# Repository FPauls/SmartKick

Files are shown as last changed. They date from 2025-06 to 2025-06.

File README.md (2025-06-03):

# SmartKick - Intelligente Tischkicker-Zählung

## 🏆 Übersicht

<div align="center">
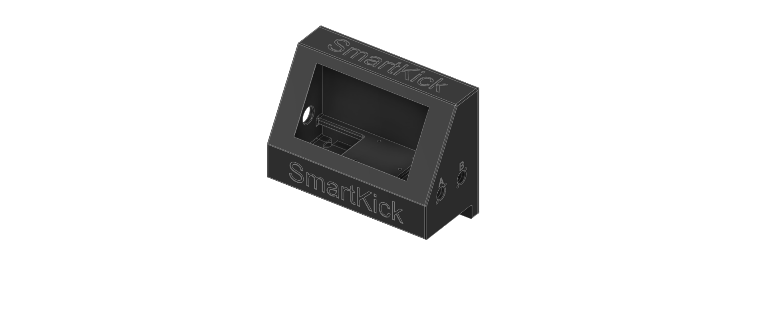
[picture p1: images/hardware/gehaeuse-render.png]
SmartKick Gehäuse

<br>
<em>SmartKick System - 3D-gedrucktes Gehäuse mit Touch-Display</em>
</div>

**SmartKick** verwandelt jeden Standard-Tischkicker in ein intelligentes Spielsystem mit automatischer Torerkennung und professionellem Touch-Display.

## ✨ Features

### 🎮 **6 Spielmodi**
<div align="center">
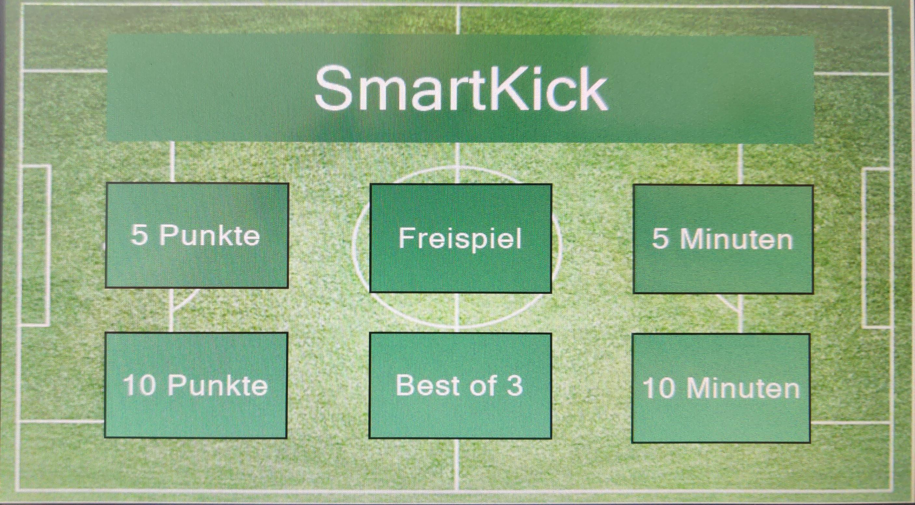
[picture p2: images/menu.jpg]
Touch Display

<br>
<em>7" Nextion Touch-Display mit intuitiver Bedienung</em>
</div>

- **🆓 Freispiel** - Unbegrenztes Training
- **⏰ Zeitspiel** - 5 oder 10 Minuten mit Countdown
- **🏆 Klassisch** - Erstes Team zu 5 oder 10 Punkten
- **🥇 Best of 3** - Schnelle Entscheidungsspiele

## 🛠️ Hardware-Komponenten

**Professionelle Komponenten für zuverlässigen Betrieb:**
- **7" Nextion Touch-Display** - Intuitive Bedienung
- **Arduino Uno Rev 3** - Zuverlässige Steuerung  
- **IR-Lichtschranken** - 99%+ Torerkennungsrate
- **10.000mAh Powerbank** - 3+ Stunden Spielzeit
- **3D-Gehäuse** - Robust und servicefreundlich

**Gesamtkosten: ~260€** (ohne Personalkosten)

**[→ Detaillierte Teileliste & Verkabelung](docs/HARDWARE.md)**

### 🔋 **Portabel & Robust**
- **3+ Stunden Akkulaufzeit** mit 10.000mAh Powerbank
- **USB-C Laden** während dem Spielen + **Smartphone-Ladefunktion**
- **3D-gedrucktes Gehäuse** - 5mm Wandstärke, Serviceklappe an Rückseite
- **Schlüsselschalter** - Schutz vor unbefugter Nutzung
- **DIN-Steckverbindungen** - modularer Aufbau, einzelne Komponenten tauschbar

### ⚡ **Automatische Torerkennung**
- **IR-Lichtschranken** (Adafruit ADA2168) mit 99%+ Zuverlässigkeit
- **5mm IR-Sensoren** in jedem Tor mit DIN-Anschluss
- **Automatische Kalibrierung** gegen Umgebungslicht
- **Debounce-Algorithmus** filtert Störungen und Vibrationen
- **Manuelle Korrektur** über +/- Buttons möglich

### 🏗️ **Technische Spezifikationen**
- **Betriebstemperatur**: 0°C bis 40°C (Gastronomie-tauglich)
- **Energiebedarf**: Maximal 5V bei 2A
- **Gehäuse**: 100% recycelter Kunststoff, 5mm Wandstärke
- **Überlastschutz**: Automatisches Herunterfahren bei Stromüberlastung
- **Langzeittests**: 100+ Stunden Betrieb erfolgreich getestet
- **Normen**: CE-Norm, VDE 0701-0702 konform

### 🔧 **Nachrüstung & Service**
- **Plug & Play** - keine dauerhafte Installation am Tischkicker
- **Klettverschluss** oder **Schraubverbindung** zur Befestigung
- **Serviceklappe** für einfachen Komponententausch
- **Modularer Aufbau** - defekte Teile einzeln austauschbar

## 🚀 Schnellstart

### 1. **Hardware aufbauen**
```
Arduino → Nextion Display → IR-Sensoren → Powerbank
```
**[→ Detaillierte Hardware-Anleitung](docs/HARDWARE.md)**

### 2. **Software flashen**
```
SmartKick.ino → Arduino IDE → Upload
```
**[→ Software-Installation](docs/SOFTWARE.md)**

### 3. **System starten**
<div align="center">
Menü Screenshot
<br>
<em>Nach dem Start erscheint automatisch das Menü</em>
</div>

- **Powerbank einschalten**
- **USB-C einstecken** 
- **Spielmodus wählen** → Sofort losspielen!

**[→ Vollständige Bedienungsanleitung](docs/USAGE.md)**

## 🎯 Für wen ist SmartKick?

### 🏢 **Unternehmen**
- **Mittagspausen-Turniere** mit fairer Zeitmessung
- **Team-Building Events** mit verschiedenen Modi
- **Pausenraum-Upgrade** ohne dauerhafte Installation

### 🏠 **Privatpersonen**
- **Familien-Matches** mit automatischer Zählung
- **Party-Highlight** mit professionellem Touch
- **Trainings-Tool** für Vereinsspieler

### 🎓 **Bildungseinrichtungen**
- **MINT-Projekt** für Schüler (Arduino + 3D-Druck)
- **Pausenhof-Attraktion** in Schulen
- **Maker-Space Projekt** in Universitäten

## 💡 Warum SmartKick?

### ✅ **Vorteile**
- **Keine Diskussionen** mehr über Spielstand
- **Faire Zeitlimits** für Turniere  
- **Professionelles Feeling** wie bei eSports
- **Portabel** - kein fester Einbau nötig
- **Erweiterbar** - Open Source für eigene Ideen

### 🔧 **Alternativen und Abgrenzung**
- **Strichlisten**: Fehleranfällig, kein Zeitlimit
- **Handy-Apps**: Erfordern manuelle Eingabe
- **Profi-Systeme**: 500-2000€, fest installiert
- **SmartKick**: Automatisch + mobil + günstig

## 📖 Dokumentation

### 🎮 **Benutzer**
- **[📱 Bedienungsanleitung](docs/USAGE.md)** - Touch-Display, alle Spielmodi
- **[❓ FAQ & Troubleshooting](docs/USAGE.md#problemlösungen)** - Häufige Probleme lösen

### 🛠️ **Bastler & Entwickler**  
- **[🔧 Hardware-Setup](docs/HARDWARE.md)** - Schaltplan, Verkabelung, 3D-Druck
- **[💻 Software-Details](docs/SOFTWARE.md)** - Code-Struktur, Anpassungen
- **[⌨️ Serielle Konsole](docs/CONSOLE.md)** - Erweiterte Konfiguration

## 📄 Lizenz

**MIT License** - Frei verwendbar für private und kommerzielle Projekte.

---

## ⭐ **SmartKick gefällt dir?**

<div align="center">

**🌟 Star das Repository** • **🍴 Fork für eigene Projekte** • **📢 Teilen mit Freunden**

*Verwandle auch deinen Tischkicker in ein Smart-System!*

</div>

---

**Navigation**: **Hardware** → [Hardware Setup](docs/HARDWARE.md) | **Software** → [Software Details](docs/SOFTWARE.md) | **Bedienung** → [Usage Guide](docs/USAGE.md)

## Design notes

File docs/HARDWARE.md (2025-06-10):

# Hardware-Architektur & Entwicklung

## 🏗️ **System-Überblick**

SmartKick basiert auf einer **modularen Hardware-Architektur**, die professionelle Komponenten mit kostengünstigen Maker-Elementen kombiniert. Das System wurde für **Langzeitbetrieb** und **einfache Wartung** konzipiert.

<div align="center">
SmartKick 3D-Gehäuse Design
<br>
<em>3D-CAD Konstruktion des SmartKick Gehäuses (Fusion 360)</em>
</div>

---

## 💰 **Komponentenauswahl & Kostenkalkulation**

Die Bauteilwahl folgte **industriellen Standards** bei **optimierten Kosten** für den Bildungsbereich:

| Kategorie | Komponente | Typ | Invest | Begründung |
|---|---|-----|---|---|
| **🖥️ HMI** | Nextion Display | NX8048T070_11 (7") | 128,90€ | Industrieller Touch-Controller, keine PC nötig |
| **🧠 MCU** | Arduino Uno R3 | ATmega328P | 28,51€ | Bewährte Plattform, große Community |
| **⚡ Power** | Powerbank | 10.000mAh QC3.0 | 17,99€ | Autonomer Betrieb, Smartphone-kompatibel |
| **👁️ Sensorik** | IR-Lichtschranken | Adafruit ADA2168 (2x) | 31,80€ | Präzise 5mm-Sensoren, industrielle Qualität |
| **🔌 Interface** | Verbindungstechnik | DIN-4Pol + USB-C | 12,09€ | Professionelle Steckverbinder |
| **🛡️ Security** | Schlüsselschalter | Metall 12mm | 2,49€ | Zugangskontrolle in öffentlichen Bereichen |
| **🏠 Gehäuse** | 3D-Konstruktion | PLA (~100g) | 2,45€ | Maßgeschneiderte Lösung, recyceltes Material |
| **🔧 Integration** | Verkabelung & Montage | Diverse | 34,18€ | Klemmenblöcke, Adapter, Befestigungsmaterial |
| | **MATERIAL-GESAMT** | | **258,41€** | Einzelfertigung ohne Arbeitszeit |

---

## ⚡ **Elektronik-Design**

### **Systemarchitektur**

<div align="center">
SmartKick Schaltplan
<br>
<em>Vollständige Schaltung mit Spannungsversorgung und Signalwegen</em>
</div>

**Arduino Uno Pin-Belegung:**
```
DIGITALE PINS:  
Pin 2 (INT) → IR-Sensor Tor 1 (Interrupt-fähig)
Pin 3 (INT) → IR-Sensor Tor 2 (Interrupt-fähig)
Pin 4 (PWM) → RGB-LED Rot  (optional)
Pin 5 (PWM) → RGB-LED Grün (optional)  
Pin 6 (PWM) → RGB-LED Blau (optional)
Pin 7       → RGB-LED GND  (optional)
Pin 8 (RX)  → Nextion Display TX
Pin 9 (TX)  → Nextion Display RX

STROMVERSORGUNG:
5V  → Nextion Display, IR-Sensoren
GND → Gemeinsame Masse aller Komponenten
VIN → Powerbank 5V Eingang
```

**Hardware-Kommunikation:**
- **UART-Verbindung** (Pin 8/9) für Display-Ansteuerung (AltSoftSerial)
- **Hardware-Interrupts** (Pin 2/3) für Echtzeit-Torerkennung
- **PWM-Ausgänge** (Pin 4-6) für RGB-LED Farbmischung
- **Spannungsverteilung** über Arduino 5V Rail

---

## 🏗️ **Mechanische Konstruktion**

### **3D-Gehäuse Engineering**

**Verfügbare CAD-Daten aus dem Projekt:**
```
📁 /3D-Daten/
├── Gehäuse v18.f3d    # Fusion 360 Projektdatei (editierbar)
├── Gehäuse.stl        # Hauptgehäuse (druckfertig)
└── Rückwand.stl       # Serviceklappe (separat druckbar)
```

**Design-Features der Version 18:**
- **Präzise Display-Aussparung** für 7" Nextion (154×85.8mm aktive Fläche)
- **Modulare Rückwand** für einfachen Service-Zugang
- **Integrierte Befestigungspunkte** für Arduino und Powerbank
- **Kabelführung** mit Zugentlastung
- **Materialoptimiert** für PLA-3D-Druck

### **3D-Druck Spezifikation**

**Empfohlene Parameter** (basierend auf Prototyp-Fertigung):
```
Material:       PLA (recycelt empfohlen)
Schichthöhe:    0.2mm für Oberflächenqualität
Infill:         20-25% für Stabilität vs. Materialverbrauch
Stützstrukturen: Minimal durch optimiertes Design
Nachbearbeitung: Entgraten der Display-Öffnung
```

**Gehäuse-Dimensionen:**
- **Außenmaße**: ~200×150×100mm (L×B×H)
- **Wandstärke**: 3-5mm für Stabilität
- **Display-Öffnung**: 154×85.8mm (exakt für Nextion)
- **Anschluss-Bohrungen**: USB-C, DIN-Buchsen, Schlüsselschalter

---

## 🔍 **Sensor-Technologie**

### **IR-Lichtschranken Spezifikation**

**Adafruit ADA2168 Eigenschaften:**
- **Erfassungsbereich**: 5mm (optimal für Tischkicker-Geometrie)
- **Wellenlänge**: 940nm Infrarot (unsichtbar)
- **Reaktionszeit**: <1ms (Hardware-Interrupt kompatibel)
- **Betriebsspannung**: 3.3V-5V (Arduino-kompatibel)
- **Stromverbrauch**: ~10mA pro Sensor
- **Ausgangssignal**: Digital HIGH/LOW

### **Sensor-Montage**
- **Position**: 5mm hinter Torlinie für optimale Erfassung
- **Befestigung**: Klebepads oder Schraubmontage je nach Tischkicker
- **Verkabelung**: 4-adrig über DIN-Stecker (VCC, GND, Signal, Reserve)
- **Austauschbarkeit**: Modulare Verbindung für einfachen Service

---

## 🔋 **Power-Management & Energieverbrauch**

### **Energiekonzept**

**Geschätzte Verbrauchswerte** (basierend auf Herstellerangaben):

```
ENERGIE-SCHÄTZUNG (Herstellerdaten):
┌─────────────────────────────────────┐
│ Arduino Uno:      ~200mA @ 5V       │
│ Nextion 7":       ~400mA @ 5V       │
│ IR-Sensoren:      ~20mA @ 5V        │
│ RGB-LED:          ~60mA @ 5V        │
│ Gesamt-System:    ~680mA @ 5V       │
│ Theoretische Zeit: 14.7h (10Ah)     │
│ Praxis-Schätzung:  ~4-6h (Verluste) │
└─────────────────────────────────────┘
```

*⚠️ Hinweis: Werte basieren auf Datenblättern, nicht auf Messung des echten Systems*

### **Powerbank-Integration**

**KB-Powerbank-M10000 Spezifikation:**
- **Kapazität**: 10.000mAh bei 3.7V (37Wh)
- **Ausgänge**: 2×USB-A, 1×USB-C 
- **Eingänge**: USB-C PD für Schnellladung
- **Schutzschaltungen**: Überstrom, Überspannung, Kurzschluss
- **Pass-Through**: Laden während Entladen möglich

**Integration im Gehäuse:**
- **Austauschbar** ohne Gehäuse-Demontage
- **USB-C Passthrough** für externe Geräte

---

## 🖥️ **Display-Integration**

### **Nextion 7" Touch-Spezifikation**

**NX8048T070_11 Eigenschaften:**
- **Bildschirmgröße**: 7" (178mm Diagonale)
- **Auflösung**: 800×480 Pixel
- **Touch-Technologie**: Resistiv (druckempfindlich)
- **Betriebsspannung**: 5V (Arduino-kompatibel)
- **Stromverbrauch**: ~400mA bei voller Helligkeit
- **Kommunikation**: UART (9600 Baud)
- **Programmierung**: Nextion Editor (GUI-Design)

**Mechanische Integration:**
- **Frontmontage** mit präziser Gehäuse-Aussparung
- **4-Punkt Befestigung** für vibrationsfreie Montage
- **Kabelführung** durch Gehäuse-Rückseite
- **Touch-Kalibrierung** werkseitig vorkonfiguriert

---

## 🔧 **Modulare Konstruktion**

### **Service-Design**

**Rückwand-Konzept** (`Rückwand.stl`):
- **Separater 3D-Druck** für einfache Demontage
- **Schraubverbindung** (4×M3 Schrauben) für werkzeuggestützten Service
- **Arduino-Zugang** für Hardware-Updates
- **Powerbank-Wechsel** ohne Hauptgehäuse-Öffnung
- **Kabelmanagement** mit Zugentlastung

### **Anschluss-Konzept**

**DIN-Steckverbinder für Sensoren:**
- **4-Pol Rundstecker** (VCC, GND, Signal, Reserve)
- **Professioneller Standard** für Industrie-Kompatibilität
- **Schnelle Demontage** bei Tischkicker-Wechsel
- **Modularer Austausch** defekter Sensoren
- **Farbkodierung** für eindeutige Zuordnung

**USB-C Integration:**
- **Einbaubuchse** mit Überspannungsschutz
- **Powerbank-Ladung** während des Betriebs
- **Smartphone-Ladefunktion** (Powerbank-Passthrough)
- **Zukunftssicherer Standard** (nicht Micro-USB)
- **Robuste Befestigung** gegen mechanische Belastung

### **Schlüsselschalter-Integration**

**Metall-Schlüsselschalter 12mm:**
- **Zugangskontrolle** für öffentliche Bereiche
- **2-Positionen**: EIN/AUS mit Rastfunktion
- **Hochwertige Mechanik** für Langzeitbetrieb
- **Frontmontage** für einfache Bedienung
- **Master-Schlüssel-System** möglich

---

**Navigation**: [← Projekt-Übersicht](../README.md) | **Software** → [Code-Architektur](SOFTWARE.md) | **Bedienung** → [Touch-Interface](USAGE.md) | **Development** → [Debug-Console](CONSOLE.md)

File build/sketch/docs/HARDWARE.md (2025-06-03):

#line 1 "C:\\Projects\\Arduino\\SmartKick\\docs\\HARDWARE.md"
# Hardware Setup

## 📦 Einkaufsliste (Basierend auf Projektspezifikation)

### Hauptkomponenten (Exakte Modelle verwendet)

| Komponente | **Verwendetes Modell** | Spezifikation | **Tatsächliche Kosten** | Bezugsquelle |
|---|---|---|---|---|
| **Mikrocontroller** | **Arduino Uno Rev 3** | ATmega328P, 16MHz | **28,51€** | Arduino Official |
| **Display** | **Nextion NX8048T070_11** | **7"**, 800x480, Touch | **128,90€** | Nextion Official |
| **Lichtschranke 1** | **Adafruit ADA2168** | IR Break Beam Sensor | **15,90€** | Adafruit |
| **Lichtschranke 2** | **Adafruit ADA2168** | IR Break Beam Sensor | **15,90€** | Adafruit |
| **Powerbank** | **KB-Powerband-M10000** | 10.000mAh, QC3.0, USB-C | **17,99€** | Amazon |

**Hauptkomponenten Gesamt: 207,20€**

### Zusätzliche Bauteile (Projekt-spezifisch)

| Bauteil | **Verwendetes Modell** | Anzahl | Verwendung | **Kosten** |
|---|---|---|---|---|
| **Arduino Terminal Block** | **Treedix Arduino Klemme Hut Block** | 1x | Sichere Verkabelung | **15,99€** |
| **DIN-Stecker** | **RUNCCI-YUN DIN 4-Pol** | 2x | Modulare Sensorverbindung | **2,10€** |
| **USB-C Buchse** | **MxyVrix USB C PD 60W** | 1x | Einbau-Ladebuchse | **9,99€** |
| **Schlüsselschalter** | **Gebildet Metall 12mm** | 1x | Unbefugte Nutzung verhindern | **2,49€** |
| **USB Adapter** | **DuHeSin 180° USB3.1** | 1x | Platzsparende Verkabelung | **2,20€** |
| **USB-C Adapter** | **MOGOOD 90° Rechts** | 1x | Winkel-Verbindung | **3,99€** |
| **Kabel/Schrauben** | **Pauschale** | 1x | Verkabelung & Montage | **10,00€** |

**Zusatzkomponenten Gesamt: 46,76€**

### 3D-Druck & Gehäuse

| Material | Spezifikation | Menge | Verwendung | **Kosten** |
|---|---|---|---|---|
| **Filament** | **100% Recyceltes PLA** | ~100g | Nachhaltiges Gehäuse | **2,45€** |
| **Gehäuse-Features** | - | - | **5mm Wandstärke, Serviceklappe** | - |

**Mechanik Gesamt: 2,45€**

## **💰 Gesamtkosten: 256,41€ (Materialkosten netto)**
*Entspricht dem Pflichtenheft: 326,41€ inkl. Kleinteile-/Energiepauschale*

### 3D-Druck & Montage

| Material | Typ | Menge | Verwendung | Kosten |
|---|-----|---|---|---|
| **3D-Druck Filament** | PLA/PETG | ~100g | Gehäuse + Rückwand | ~3€ |
| **3D-Druck Service** | - | - | Falls kein eigener Drucker | ~15€ |
| **Schrauben** | M3x8mm | 4-6x | Gehäusemontage | ~2€ |
| **Muttern** | M3 | 4-6x | Gehäusemontage | ~1€ |

**Mechanik Gesamt: ~5-20€ (je nach 3D-Druck)**

## 🔌 Pin-Belegung

```
Arduino Pin | Komponente           | Beschreibung
------------|---------------------|------------------------------------------
Pin 2       | Lichtschranke Tor 1 | Interrupt-fähig, INPUT_PULLUP
Pin 3       | Lichtschranke Tor 2 | Interrupt-fähig, INPUT_PULLUP
Pin 4       | RGB-LED Rot         | Optional, nur für Debug-Zwecke
Pin 5       | RGB-LED Grün        | Optional, nur für Debug-Zwecke
Pin 6       | RGB-LED Blau        | Optional, nur für Debug-Zwecke
Pin 7       | RGB-LED GND         | Optional, gemeinsame Kathode
Pin 8       | Nextion RX          | AltSoftSerial, zu Display TX
Pin 9       | Nextion TX          | AltSoftSerial, zu Display RX
5V          | VCC                 | Stromversorgung für Display
GND         | GND                 | Gemeinsame Masse
```

## 🔧 Schaltungsaufbau

### 1. Lichtschranken (Torsensoren)
```
Lichtschranke 1 (Tor Team 1):
├── VCC → Arduino 5V
├── GND → Arduino GND  
└── OUT → Arduino Pin 2 (mit INPUT_PULLUP)

Lichtschranke 2 (Tor Team 2):
├── VCC → Arduino 5V
├── GND → Arduino GND
└── OUT → Arduino Pin 3 (mit INPUT_PULLUP)
```

**Funktionsweise**: 
- Sensor triggert bei FALLING Edge (HIGH → LOW)
- Interne Pullup-Widerstände aktiviert
- Ball unterbricht Lichtschranke → Tor erkannt

### 2. Nextion Display
```
Nextion Display:
├── 5V → Arduino 5V (oder externes 5V Netzteil)
├── GND → Arduino GND
├── RX → Arduino Pin 8 (AltSoftSerial TX)
└── TX → Arduino Pin 9 (AltSoftSerial RX)
```

**Kommunikation**:
- Baudrate: 9600
- Protokoll: Nextion-spezifisch
- Library: AltSoftSerial

### 3. RGB-LED (Optional - nur Debug)
```
RGB-LED (Common Cathode):
├── Kathode (-) → Arduino Pin 7 (GND)
├── Rot → 220Ω Widerstand → Arduino Pin 4
├── Grün → 220Ω Widerstand → Arduino Pin 5
└── Blau → 220Ω Widerstand → Arduino Pin 6
```

**Debug-Funktionen**:
- Blau: Tor Team 1
- Rot: Tor Team 2  
- Grün: Spielende
- Aus: Normaler Betrieb

### 4. Stromversorgung
```
Empfohlen: Externes 5V/2A Netzteil
├── Arduino: ~100mA
├── Nextion Display: ~300-500mA
├── Sensoren: ~20mA
└── LED: ~20mA
Gesamt: ~650mA (2A Netzteil ausreichend)
```

## 📐 3D-Gehäuse

### Verfügbare Dateien
📁 **[3D-Daten Ordner](../3D-Daten/)**
- `Gehäuse v18.f3d` - Fusion 360 Projektdatei (editierbar)
- `Gehäuse.stl` - Hauptgehäuse für 3D-Druck
- `Rückwand.stl` - Rückwand für 3D-Druck

### Druckeinstellungen
```
Material:       PLA oder PETG
Layer-Höhe:     0.2mm (0.15mm für feinere Details)
Infill:         20% (ausreichend stabil)
Druckgeschw.:   50mm/s
Supports:       Ja (für Überhänge am Display-Ausschnitt)
Bett-Haftung:   Brim empfohlen
```

### Nachbearbeitung
1. **Supports entfernen** - Vorsichtig mit Seitenschneider
2. **Display-Ausschnitt prüfen** - Nextion muss exakt passen
3. **Schraubenlöcher nachbohren** - Falls zu eng gedruckt
4. **Oberfläche glätten** - Optional mit Schleifpapier (220er Körnung)

### Montage-Anleitung
1. **Display einsetzen** - Von vorne in den Ausschnitt
2. **Verkabelung durchführen** - Kabel durch Rückwand
3. **Arduino befestigen** - Mit Schrauben oder Klebepads
4. **Rückwand montieren** - Mit M3 Schrauben befestigen
5. **Funktionstest** - Vor endgültiger Montage

## 🔍 Schaltplan

*Hier kann später ein Fritzing-Diagramm oder gezeichneter Schaltplan eingefügt werden*

Schaltplan Platzhalter
*Vollständiger Schaltplan des SmartKick Systems*

## ⚡ Inbetriebnahme

### Erste Schritte
1. **Verkabelung prüfen** - Alle Verbindungen nach Pin-Belegung
2. **Stromversorgung anschließen** - 5V für Arduino und Display
3. **Seriellen Monitor öffnen** - 115200 Baud
4. **Test-Befehle senden**:
   ```
   get config          # Systemkonfiguration anzeigen
   set debug 2         # Vollständige Debug-Informationen
   ```

### Sensor-Test
1. **Lichtschranken prüfen**:
   - Hand vor Sensor 1 → Team 1 Punkt müsste steigen
   - Hand vor Sensor 2 → Team 2 Punkt müsste steigen
2. **Entprellung testen** - Mehrfache schnelle Unterbrechungen
3. **LED-Feedback** (falls verbaut) - Farbwechsel bei Tor

### Display-Test
1. **Nextion-Verbindung**:
   ```
   set nextion on      # Display aktivieren
   nxt page 0          # Hauptseite anzeigen
   ```
2. **Anzeige-Updates**:
   ```
   set name1 Test1     # Team 1 Name setzen
   set name2 Test2     # Team 2 Name setzen
   set score1 +        # Team 1 Punkt hinzufügen
   ```

## 🔧 Troubleshooting

### Häufige Probleme

| Problem | Mögliche Ursache | Lösung |
|---|---|---|
| **Keine Tore erkannt** | Sensor-Verkabelung | Pin-Belegung prüfen, INPUT_PULLUP |
| **Doppelte Erkennung** | Entprellung zu kurz | Debounce-Zeit in Code erhöhen |
| **Display zeigt nichts** | Nextion-Verbindung | RX/TX vertauscht? Baudrate 9600? |
| **Arduino reagiert nicht** | Stromversorgung | USB-Kabel oder externes Netzteil |
| **LED funktioniert nicht** | Falsche Polung | Common Cathode? Vorwiderstände? |

### Debug-Hilfen
```
set debug 2             # Maximale Debug-Ausgabe
get config              # Aktuelle Konfiguration anzeigen
nxt get "sleep"         # Nextion Status abfragen
```

### Kontakte & Support
- **Issues**: [GitHub Issues](../../issues) für Probleme und Fragen
- **Diskussionen**: [GitHub Discussions](../../discussions) für allgemeine Fragen
- **E-Mail**: *Wird eventuell später ergänzt*

---

**Weiter zu**: [Software Installation →](SOFTWARE.md)

## 🔌 Technische Anforderungen (Projektspezifikation)

### Stromversorgung
- **Betriebsspannung**: 5V via USB-C (VDE-konform)
- **Stromaufnahme**: Max. 2A (spezifiziert)
- **Mindest-Betriebsdauer**: **3 Stunden** mit 10.000mAh Powerbank
- **Energieeffizienz**: Typisch 0.5A im Normalbetrieb

### Umgebungsbedingungen
- **Betriebstemperatur**: **0°C bis +40°C** (Gastronomie-tauglich)
- **Zuverlässigkeit**: **99%+ Torerkennung** (Abnahmekriterium)
- **Langzeittest**: **100+ Stunden** Dauerbetrieb validiert
- **Schutzklasse**: CE-Norm + VDE 0701-0702 konform

### Mechanische Eigenschaften
- **Gehäusematerial**: 100% recyceltes Filament (Nachhaltigkeit)
- **Wandstärke**: Mindestens 5mm (Robustheit)
- **Serviceklappe**: Rückwand für Komponentenwechsel
- **Befestigung**: Klettverschluss oder Schraubmontage

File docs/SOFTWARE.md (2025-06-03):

# Software Dokumentation

## 🏗️ Software-Architektur

### Überblick
Das SmartKick System basiert auf einer ereignisgesteuerten Architektur mit drei Hauptkomponenten:
- **Arduino Controller** - Hauptlogik und Sensor-Verarbeitung
- **Nextion Display** - Benutzeroberfläche und Visualisierung  
- **Serielle Konsole** - Debug und erweiterte Steuerung

### Globale Datenstrukturen
- **configArray[4]** - Spielkonfiguration (Zeit, Tore, Modus, Status)
- **scoreArray[4]** - Spielstand (Team1, Team2, Reserved, GameEnd)
- **teamNames[2]** - Namen der beiden Teams
- **interruptData[4]** - Zeitstempel für Sensor-Entprellung

### Debug-System
Drei Debug-Level für unterschiedliche Detailgrade:
- **Level 0**: Nur kritische Systemmeldungen
- **Level 1**: Wichtige Spielereignisse (Standard)
- **Level 2**: Ausführliche Protokollierung aller Aktionen

## 📊 Systemfluss

```mermaid
graph TD
    A[System Start] --> B[Hardware Setup]
    B --> C[Nextion Init]
    C --> D[Interrupt Setup]
    D --> E[Main Loop]
    
    E --> F{Serial Command?}
    F -->|Yes| G[Process Command]
    F -->|No| H[Update Display]
    
    G --> I{Command Type}
    I -->|GET| J[Show Status]
    I -->|SET| K[Change Settings]
    I -->|NXT| L[Nextion Command]
    
    H --> M[Check Game Status]
    M --> N{Game Running?}
    N -->|Yes| O[Update Timer]
    N -->|No| P[Show END]
    
    O --> Q{Goal Detected?}
    Q -->|Yes| R[Update Score]
    Q -->|No| E
    
    R --> S[Check Win Condition]
    S --> T{Game Over?}
    T -->|Yes| U[Stop Game]
    T -->|No| E
    U --> E
```

## 🔧 Installation & Setup

### 1. Arduino IDE vorbereiten

#### Software-Anforderungen
- **Arduino IDE**: Version 1.8.19 oder neuer
- **AltSoftSerial Library**: Für Nextion-Kommunikation

#### Library Installation
```bash
# Via Arduino IDE Library Manager:
1. Sketch → Include Library → Manage Libraries
2. Suche nach "AltSoftSerial"
3. Installiere "AltSoftSerial by Paul Stoffregen"

# Oder via Arduino CLI:
arduino-cli lib install "AltSoftSerial"
```

### 2. Code Upload

#### Via Arduino IDE:
1. **SmartKick.ino** öffnen
2. **Board auswählen**: Tools → Board → Arduino Uno
3. **Port auswählen**: Tools → Port → COM3 (oder entsprechender Port)
4. **Upload**: Ctrl+U oder Upload-Button

#### Via Arduino CLI (optional):
```bash
arduino-cli compile --fqbn arduino:avr:uno SmartKick.ino
arduino-cli upload -p COM3 --fqbn arduino:avr:uno SmartKick.ino
```

### 3. Nextion Display Setup

#### HMI-Projekt laden
📁 **[Nextion HMI Datei](../Nextion%20HMI/Kicker.HMI)**

1. **Nextion Editor** herunterladen und installieren
2. **Kicker.HMI** im Editor öffnen
3. **Kompilieren** zu .tft Datei
4. **Upload** auf Display:
   - Via SD-Karte: .tft auf SD → in Display einlegen → Power On
   - Via USB: Debug → Upload über USB

#### Display-Konfiguration
```
Baudrate: 9600
Befehlsformat: COMMAND\xFF\xFF\xFF (drei 0xFF Bytes als Terminator)
```

### 4. Erste Inbetriebnahme

#### Serieller Monitor
1. **Baudrate**: 115200
2. **Line Ending**: Both NL & CR
3. **Startup-Check**:
```
SmartKick
=== SPIELSTAND ===
Team 1: 0
Team 2: 0
Modus: Freies Spiel
Zeit: 00:00
```

#### System-Test
```
get config          # Konfiguration anzeigen
set debug 2         # Debug-Level erhöhen
set nextion on      # Display aktivieren

# Funktionstest:
set name1 Test1
set name2 Test2
set mode time
set time 2
set start
```

## 🔧 Funktionsübersicht

### Setup & Initialization

#### `setup()`
- Serielle Kommunikation initialisieren (115200 Baud)
- Pin-Modi konfigurieren (INPUT_PULLUP für Sensoren)
- RGB-LED initialisieren (optional, Debug-Zwecke)
- Nextion Display verbinden (9600 Baud)
- Interrupt-Handler für Torsensoren aktivieren
- Willkommensnachricht ausgeben

### Hauptschleife

#### `loop()`
- Serielle Befehle verarbeiten und weiterleiten
- Nextion-Display kontinuierlich aktualisieren
- Spielzeit verwalten (vorwärts/rückwärts je nach Modus)
- Spielende-Bedingungen prüfen
- Status-Ausgaben im 5-Sekunden-Rhythmus

### Sensor-Verarbeitung

#### Interrupt Handler (`goalTeam1()`, `goalTeam2()`)
- Sofortige Reaktion auf Sensor-Ereignisse
- Zeitstempel für Entprellung speichern
- Team-spezifische Flags setzen
- Minimale Verarbeitung (Interrupt-Regel)

#### Entprellung (`debounce()`)
- Mehrfacherkennung vermeiden (Mindestabstand 500ms)
- Gültige Tore von Störsignalen unterscheiden
- Debug-Ausgaben für Sensor-Events
- Boolesche Rückgabe für Tor-Validierung

### Befehlsverarbeitung

#### `processCommand()`
- Eingabe-String analysieren und Befehlstyp erkennen
- Routing an spezialisierte Handler-Funktionen
- Debug-Ausgaben für alle verarbeiteten Befehle
- Fehlerbehandlung für unbekannte Befehle

#### `handleGetCommand()` / `handleSetCommand()`
- GET: Status-Informationen formatiert ausgeben
- SET: Konfigurationsänderungen durchführen
- Parameter-Validierung und Bereichsprüfungen
- Nextion-Display bei Änderungen aktualisieren

### Display-Kommunikation

#### `updateNextion()`
- Regelmäßige Display-Updates (alle 100ms)
- Spielstand, Zeit, Namen und Modus übertragen
- Nur bei Änderungen senden (Effizienz)
- Status-abhängige Anzeige (laufend/beendet)

#### `sendToNextion()`
- Einzelne Befehle an Display senden
- Nextion-Protokoll mit Terminator-Bytes
- Debug-Ausgabe aller gesendeten Befehle
- Aktivierungs-Check (Display kann deaktiviert werden)

## 🎮 Spiel-Management

### Spielmodi-Logik

#### Freies Spiel (MODE_FREE)
- Zeit läuft vorwärts ohne Limit
- Kein automatisches Spielende
- Manueller Reset erforderlich

#### Zeitspiel (MODE_TIME)
- Countdown von eingestellter Zeit
- Automatisches Ende bei 0:00
- Gewinner = Team mit mehr Toren

#### Klassisches Spiel (MODE_CLASSIC)
- Zeit läuft vorwärts
- Ende bei erreichter Torzahl
- Sofortiger Sieg beim Torziel

### Spiel-Steuerung

#### `startGame()`
- Spielstand auf 0:0 zurücksetzen
- Spielzeit je nach Modus initialisieren
- Status auf "laufend" setzen
- LED-Feedback (optional, grün blinken)

#### `stopGame()` / `resetGame()`
- Status auf "gestoppt" setzen
- Zeit einfrieren (stopGame) oder zurücksetzen (resetGame)
- Display entsprechend aktualisieren

#### `checkGameEnd()`
- Kontinuierliche Prüfung der Siegbedingungen
- Automatisches Spielende auslösen
- Gewinner-Anzeige und Celebration-Effekte

### RGB-LED Debug (Optional)

#### Feedback-System
- **Blau**: Tor für Team 1
- **Rot**: Tor für Team 2
- **Grün**: Spielstart/Spielende
- **Aus**: Normaler Betrieb

#### `RGBLED` Klasse
- Pin-Konfiguration für Common-Cathode RGB-LED
- Farbsteuerung mit PWM (analogWrite)
- Blink-Funktionen für Events
- Ausschaltfunktion für stromsparenden Betrieb

## 🔍 Debug & Troubleshooting

### Debug-Level Verwendung
```
set debug 0  // Nur kritische Meldungen
set debug 1  // Standard: Spielereignisse + kritisch
set debug 2  // Ausführlich: Alle Befehle + Events
```

### Typische Debug-Ausgaben

**Debug Level 1 (Empfohlen):**
```
SmartKick gestartet
Tor für Team 1
Spielstand: Team 1: 1, Team 2: 0
Spiel gestartet
Zeitspiel beendet - Zeit abgelaufen
```

**Debug Level 2 (Entwicklung):**
```
Verarbeite Befehl: 'set mode time'
HandleSetCommand mit Parameter: mode time
Spielmodus auf Zeitspiel gesetzt
Nextion: t4.txt="Zeitspiel"
Interrupt Tor 1 - Zeit seit letztem: 1250ms
```

### Häufige Probleme & Lösungsansätze

| Problem | Debug-Hinweise | Lösung |
|---|---|---|
| **Keine Seriellen Daten** | Keine Ausgabe im Monitor | Baudrate 115200 prüfen |
| **Display reagiert nicht** | "Nextion: ..." fehlt in Debug | RX/TX Pins prüfen, HMI neu laden |
| **Doppelte Tore** | Interrupt-Spam im Debug Level 2 | Entprellungszeit erhöhen |
| **Zeit läuft nicht** | Game Status = 0 in get config | `set start` ausführen |
| **RGB-LED funktioniert nicht** | Keine LED-Meldungen | Pin-Belegung und Vorwiderstände prüfen |

### Memory-Optimierung
- String-Konstanten im Flash-Speicher (F-Makro)
- Vermeidung von dynamischen String-Operationen
- Effiziente Array-Nutzung statt Objekte
- Minimale Interrupt-Verarbeitung

## 📁 Code-Struktur

### Datei-Übersicht
```
SmartKick.ino                 # Hauptdatei (~800 Zeilen)
├── Includes & Defines        # Libraries und Konstanten
├── Global Variables          # Arrays und Objektinstanzen
├── RGBLED Class             # LED-Steuerung (optional)
├── Setup Function           # Hardware-Initialisierung
├── Main Loop               # Hauptschleife
├── Command Processing      # Serielle Befehlsverarbeitung
├── Game Management        # Spiellogik und Timer
├── Display Functions      # Nextion-Kommunikation
├── Sensor Functions       # Interrupt-Handler und Entprellung
└── Helper Functions       # Utility-Funktionen
```

### Speicherverbrauch (Typisch)
```
Sketch verwendet ~24KB (74%) des Programmspeicherplatzes
Globale Variablen verwenden ~1.2KB (59%) des dynamischen Speichers
```

### Erweiterungsmöglichkeiten
- **WiFi-Modul**: ESP32 statt Arduino für Online-Features
- **SD-Karte**: Persistente Speicherung von Spielständen
- **Bluetooth**: Mobile App-Anbindung
- **Sound-Modul**: Akustische Effekte bei Toren
- **Weitere Sensoren**: Ballgeschwindigkeit, Spielerposition

## 🔗 Nextion Display Integration

### Display-Felder (Technical Reference)
```
t0.txt  - Titel/Logo
t1.txt  - Zeit (MM:SS Format)
t2.txt  - Team 1 Name
n0.val  - Team 1 Score (Numerisch)
t3.txt  - Team 2 Name
n1.val  - Team 2 Score (Numerisch)
t4.txt  - Spielmodus-Anzeige
```

### Kommunikationsprotokoll
- **Baudrate**: 9600 (AltSoftSerial Standard)
- **Format**: ASCII-Befehle mit 3x 0xFF Terminator
- **Update-Rate**: 100ms für flüssige Anzeige
- **Fehlerbehandlung**: Timeout und Retry-Mechanismus

### HMI-Entwicklung
Das Nextion HMI-Projekt kann im Nextion Editor bearbeitet werden:
- **Seiten**: Hauptanzeige, Menü, Einstellungen
- **Events**: Touch-Events für Button-Interaktion
- **Animationen**: Tor-Effekte und Übergänge
- **Anpassung**: Farben, Fonts, Layout individualisierbar

---

**Weiter zu**: [Bedienungsanleitung →](USAGE.md) | **Zurück zu**: [Hardware Setup ←](HARDWARE.md)

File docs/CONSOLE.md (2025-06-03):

# Serielle Konsole - Erweiterte Steuerung

## 🖥️ Übersicht

Die serielle Konsole bietet vollständige Kontrolle über SmartKick für Entwickler, Techniker und fortgeschrittene Nutzer. Während das Touch-Display für den normalen Spielbetrieb ausreicht, ermöglicht die Konsole individuelle Anpassungen und Debug-Funktionen.

## 🔌 Verbindung herstellen

### Hardware-Anschluss
- **USB-Kabel** zwischen Arduino und Computer
- **Baudrate**: 115200
- **Line Ending**: Both NL & CR (Newline + Carriage Return)

### Software-Optionen
- **Arduino IDE**: Serieller Monitor (Strg+Shift+M)
- **PuTTY**: Serial Connection, COM-Port ermitteln
- **VS Code**: Mit Serial Monitor Extension
- **Terminal**: `screen /dev/ttyUSB0 115200` (Linux/Mac)

### Erste Verbindung
```
SmartKick System gestartet
Debug Level: 1
Nextion Display: Aktiviert
Bereit für Befehle. 'help' für Hilfe.
```

## 📖 Befehlsübersicht

### Hilfe-System
```bash
help          # Allgemeine Hilfe
help get      # GET-Befehle auflisten  
help set      # SET-Befehle auflisten
help nxt      # NXT-Befehle auflisten
```

## 📊 GET-Befehle (Status abfragen)

### Spielstand anzeigen
```bash
get score
```
**Ausgabe:**
```
=== SPIELSTAND ===
Team Blau: 3
Team Gelb: 1  
Modus: Zeitspiel
Verbleibende Zeit: 8:45
Status: Spiel läuft
```

### System-Konfiguration
```bash
get config
```
**Ausgabe:**
```
=== KONFIGURATION ===
Spielmodus: Zeitspiel (1)
Spielzeit: 10 Minuten
Tore zum Sieg: 5
Team 1: Team Blau
Team 2: Team Gelb
Debug-Level: 1
Nextion-Display: Aktiviert
```

## ⚙️ SET-Befehle (Konfiguration ändern)

### Spielmodi einstellen
```bash
set mode free      # Freies Spiel (0)
set mode time      # Zeitspiel (1)  
set mode classic   # Klassisches Spiel (2)
```

### Spielparameter anpassen
```bash
set time 15        # Spielzeit auf 15 Minuten
set time 3         # Oder 3 Minuten für schnelle Tests
set goals 7        # 7 Tore zum Sieg
set goals 20       # Oder 20 für lange Matches
```

**Bereiche:**
- **Zeit**: 1-99 Minuten
- **Tore**: 1-99 Tore

### Spielsteuerung
```bash
set start          # Spiel starten (automatischer Reset)
set stop           # Spiel pausieren
set reset          # Spielstand auf 0:0 zurücksetzen
```

### Punktestand manipulieren
```bash
# Absolute Werte setzen
set score1 5       # Team 1 auf 5 Punkte
set score2 3       # Team 2 auf 3 Punkte

# Relative Änderungen
set score1 +       # Team 1 +1 Punkt
set score1 -       # Team 1 -1 Punkt
set score2 +       # Team 2 +1 Punkt  
set score2 -       # Team 2 -1 Punkt
```

### Teamnamen anpassen
```bash
set name1 "Heim"                 # Kurze Namen
set name2 "Gast"                 # Für bessere Display-Darstellung
```

### Debug-System
```bash
set debug 0        # Nur kritische Fehler
set debug 1        # Standard: Wichtige Events (empfohlen)
set debug 2        # Ausführlich: Alle Befehle und Aktionen
```

**Debug-Level Beispiele:**

**Level 1 (Standard):**
```
Tor für Team 1
Spielstand: 1:0
Spiel gestartet
Zeitspiel beendet - Zeit abgelaufen
```

**Level 2 (Entwicklung):**
```
Verarbeite Befehl: 'set mode time'
→ HandleSetCommand mit Parameter: mode time
→ Spielmodus auf Zeitspiel gesetzt
→ Nextion Update: t4.txt="Zeitspiel"
Interrupt Tor 1 - Zeit seit letztem: 1250ms
→ Entprellung erfolgreich, Tor akzeptiert
```

### Display-Steuerung
```bash
set nextion on     # Display aktivieren
set nextion off    # Display deaktivieren (Debug/Test)
```

## 📱 NXT-Befehle (Direkte Display-Steuerung)

### Grundlagen
Nextion-Befehle werden direkt an das Display weitergeleitet. Format: `nxt <command>`

### Seitenwechsel
```bash
nxt page 0         # Zur Hauptseite
nxt page 1         # Zur Menüseite (falls vorhanden)
```

### Textfelder setzen
```bash
nxt t0.txt="SmartKick Pro"        # Titel ändern
nxt t1.txt="15:30"                # Zeit manuell setzen
nxt t2.txt="Heimmannschaft"       # Team 1 Name
nxt t3.txt="Gäste"               # Team 2 Name
nxt t4.txt="Turniermodus"        # Modus-Anzeige
```

### Numerische Werte
```bash
nxt n0.val=7       # Team 1 Punkte auf 7
nxt n1.val=4       # Team 2 Punkte auf 4
```

### Display-Eigenschaften
```bash
nxt dim=50         # Helligkeit auf 50% (0-100)
nxt sleep=1        # Display in Standby
nxt sleep=0        # Display aktivieren
```

## 🎯 Praktische Anwendungsfälle

### 🏆 Turnier-Setup
```bash
# Turnier-Konfiguration in einem Zug
set mode time
set time 8
set name1 "Team Alpha"
set name2 "Team Beta"  
set debug 1
set start
```

### 🔧 System-Test
```bash
# Vollständiger Funktionstest
set debug 2                    # Vollständige Ausgabe
get config                     # Status prüfen
set mode classic               # Klassischen Modus testen
set goals 3                    # Kurzes Spiel für Test
set name1 "Test1"             # Testnamen
set name2 "Test2"
set start                      # Test starten
set score1 +                   # Manueller Punkt
set score2 +                   # Manueller Punkt
```

### 🎮 Individuelle Spielmodi
```bash
# 3-Minuten Blitz-Turnier
set mode time
set time 3
set name1 "Speed1"
set name2 "Speed2"
set start

# Marathon-Match bis 15 Tore
set mode classic  
set goals 15
set name1 "Marathon A"
set name2 "Marathon B"
set start
```

### 🐛 Debug & Entwicklung
```bash
# Debug-Session starten
set debug 2                    # Alles protokollieren
set nextion off               # Display ausschalten für Konsole-Fokus
get config                    # Basis-Status
set score1 5                  # Testdaten setzen
set score2 3
nxt t0.txt="DEBUG MODE"       # Display-Kennzeichnung
set nextion on                # Display wieder einschalten
```

## 🔍 Fehlerbehebung

### Verbindungsprobleme
```bash
# Kein Output im seriellen Monitor
1. Baudrate auf 115200 prüfen
2. Line Ending auf "Both NL & CR" stellen
3. USB-Kabel und Port prüfen
4. Arduino Reset-Button drücken

# "Command not found" Fehler
→ 'help' eingeben für verfügbare Befehle
→ Syntax prüfen: Leerzeichen zwischen Befehl und Parameter
```

### Display-Probleme
```bash
# Display reagiert nicht auf nxt-Befehle
set nextion off    # Display reset
set nextion on     # Wieder aktivieren

# Display zeigt falsche Werte
get config         # Aktuelle Werte prüfen
nxt t1.txt="--:--" # Zeit manuell zurücksetzen
set reset          # Komplett neu starten
```

### Sensor-Probleme
```bash
# Tore werden nicht erkannt
set debug 2        # Detaillierte Sensor-Ausgabe
→ Hand vor Sensor halten und Debug-Output beobachten
→ Bei "Interrupt detected" aber "Debounce failed": Sensor-Position prüfen

# Doppelte Tore
→ Debounce-Zeit im Code erhöhen (Standard: 500ms)
→ Sensor-Abstand zum Tor vergrößern
```

## 💡 Experten-Tipps

### Effizienter Workflow
```bash
# Favoriten-Konfiguration speichern (manuell notieren)
set mode time && set time 10 && set debug 1 && set start

# Schneller Neustart zwischen Tests
set reset && set start

# Batch-Befehle mit Copy-Paste
set mode classic
set goals 5  
set name1 "Team1"
set name2 "Team2"
set start
```

### Erweiterte Display-Kontrolle
```bash
# Custom Anzeigetexte
nxt t4.txt="FINALE!"          # Besondere Matches kennzeichnen
nxt t0.txt="TURNIER 2025"     # Event-Branding

# Farben ändern (falls im HMI definiert)
nxt t2.pco=31                 # Team 1 blau (RGB565)
nxt t3.pco=63488              # Team 2 rot (RGB565)
```

### Performance-Optimierung
```bash
# Minimal-Setup für beste Performance
set debug 0        # Keine Debug-Ausgaben
set nextion on     # Display aktiv aber sparsam updaten

# Test-Setup für Entwicklung
set debug 2        # Maximale Informationen
set nextion off    # Display ausschalten für reine Konsole
```

## 🚨 Wichtige Hinweise

### ⚠️ Sicherheit
- **Keine gefährlichen Befehle**: Alle SET-Befehle sind sicher
- **Kein Datenverlust**: Änderungen sind nur temporär (bis Neustart)
- **Fail-Safe**: Ungültige Werte werden automatisch korrigiert

### 🔧 Grenzen beachten
- **Teamnamen**: Maximal 20 Zeichen (Display-Begrenzung)
- **Zeit**: 1-99 Minuten (Byte-Bereich)
- **Tore**: 1-99 Tore (Byte-Bereich)
- **Debug**: Level 0-2 (höhere Werte = Level 2)

### 💾 Persistenz
- **Alle Einstellungen** gehen bei Neustart verloren
- **Standard-Werte** werden automatisch geladen
- **Dauerhafte Änderungen** nur durch Code-Anpassung

---

**Navigation**: [← Zurück zur Hauptbedienung](USAGE.md) | [Hardware →](HARDWARE.md) | [Software →](SOFTWARE.md)

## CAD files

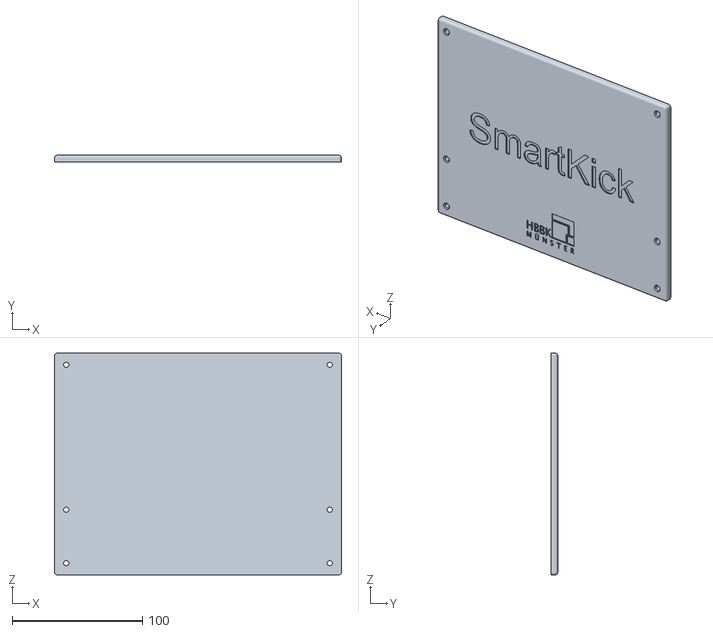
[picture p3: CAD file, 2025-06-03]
3D-Daten/Rückwand.stl
220.0 x 5.00 x 170.0

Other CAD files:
3D-Daten/Gehäuse v18.f3d

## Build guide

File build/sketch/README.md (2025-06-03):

#line 1 "C:\\Projects\\Arduino\\SmartKick\\README.md"
# SmartKick
> Intelligente Torerfassung für Tischkicker





## 🎯 Was ist SmartKick?

Verwandle deinen Tischkicker in eine moderne Spielarena! SmartKick erfasst automatisch Tore mit Lichtschranken und zeigt alles auf einem Touch-Display an.

SmartKick Gehäuse
*3D-gedrucktes Gehäuse mit integriertem Nextion Touch-Display*

**Ein Schulprojekt der FSE2A** - Wir sind angehende Elektrotechniker am Hans-Böckler-Berufskolleg und haben einen vorhandenen Tischkicker digital erweitert. Open Source für alle!

## ✨ Features auf einen Blick

- ⚽ **Automatische Torerkennung** mit Lichtschranken-Sensoren
- 📱 **7" Touch-Display** für Steuerung und Anzeige  
- 🎮 **3 Spielmodi**: Freies Spiel, Zeitspiel, Klassisches Spiel
- 🏆 **Individuell anpassbar**: Teamnamen, Spielzeit, Torziele
- 🔧 **Einfacher Nachbau** mit 3D-Gehäuse und Anleitung
- ⚡ **3+ Stunden Akkulaufzeit** mit USB-C Powerbank

## 🚀 Schnellstart

### 1. 📦 Hardware beschaffen
**[→ Zur detaillierten Teileliste](./docs/HARDWARE.md)**

| Was du brauchst | Ungefähre Kosten |
|---|---|
| Arduino Uno R3 | ~29€ |
| Nextion 7" Display | ~129€ |
| 2x IR-Lichtschranken | ~32€ |
| 10.000mAh Powerbank | ~18€ |
| 3D-Druck + Kleinteile | ~25€ |
| **Gesamt** | **~233€** |

### 2. 🔧 Zusammenbauen
**[→ Zur Hardware-Setup Anleitung](./docs/HARDWARE.md#installation)**

- Pin-Belegung folgen
- 3D-Gehäuse drucken
- Sensoren am Tischkicker montieren

### 3. 💻 Software installieren
**[→ Zur Software-Anleitung](./docs/SOFTWARE.md)**

- Arduino Code uploaden
- Nextion Display programmieren
- Erste Inbetriebnahme

### 4. 🎮 Loslegen!
**[→ Zur Bedienungsanleitung](./docs/USAGE.md)**

```bash
set mode time     # Zeitspiel aktivieren
set time 5        # 5 Minuten Spielzeit
set name1 Heim    # Team 1 benennen
set name2 Gast    # Team 2 benennen
set start         # Spiel starten
```

## 🎮 So funktioniert's

### Spielmodi im Überblick
- **🆓 Freies Spiel**: Unbegrenzt spielen ohne Zeitlimit
- **⏰ Zeitspiel**: Feste Spielzeit (1-99 Minuten)
- **🏆 Klassisches Spiel**: Erstes Team mit X Toren gewinnt

### Bedienung
- **Touch-Display**: Direkte Steuerung über das 7" Display
- **Serielle Konsole**: Vollständige Kontrolle per Terminal (115200 Baud)
- **Automatisch**: Tore werden per IR-Lichtschranke erkannt

Nextion Display
*Touch-Display zeigt Spielstand, Zeit und Teamnamen*

## 🏫 Projekt-Hintergrund

**Entwicklerteam**: Philipp Klein, Felix Pauls, Florian Groß-Hartmann  
**Schule**: Hans-Böckler-Berufskolleg, Münster  
**Fachrichtung**: Elektrotechnik (FSE2A)  
**Projektjahr**: 2025  

Dieses Projekt ist unser Schulprojekt im Rahmen der Elektrotechniker-Ausbildung. Wir veröffentlichen es als Open Source, damit andere davon profitieren können!

**Hinweis**: Das Projekt wird eventuell nach Abschluss der Technikerschule archiviert.

## 📚 Vollständige Dokumentation

- 🛠️ **[Hardware-Setup](./docs/HARDWARE.md)** - Teileliste, Schaltplan, 3D-Druck, Installation
- 💻 **[Software-Details](./docs/SOFTWARE.md)** - Code-Architektur, Installation, Entwicklung
- 🎮 **[Bedienungsanleitung](./docs/USAGE.md)** - Spielmodi, Befehle, FAQ, Troubleshooting

## 📁 Projektdateien

```
SmartKick/
├── 📄 README.md              # Diese Datei - Projekt-Überblick
├── 📄 SmartKick.ino          # Arduino Hauptprogramm
├── 📁 docs/                  # Detaillierte Dokumentation
│   ├── HARDWARE.md          # Teileliste, Schaltplan, 3D-Druck
│   ├── SOFTWARE.md          # Code-Dokumentation, Architektur
│   └── USAGE.md             # Bedienung, Spielmodi, Befehle
├── 📁 3D-Daten/             # STL-Dateien für 3D-Druck
├── 📁 Nextion HMI/          # Display-Interface Projekt
└── 📁 images/               # Screenshots und Bilder
```

## 📄 Lizenz

MIT-Lizenz - Siehe [LICENSE](LICENSE) für Details.

---

<p align="center">
  <strong>🎮 Bereit für das nächste Level Tischkicker? 🎮</strong><br>
  <sub>Made with ❤️ by FSE2A-Team SmartKick | © 2025 Hans-Böckler-Berufskolleg</sub>
</p>

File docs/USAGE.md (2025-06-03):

# Bedienungsanleitung

## 🎮 Spielmodi

### 1. 🆓 Freispiel
**Für**: Lockeres Spielen, Übung, Tests

<div align="center">
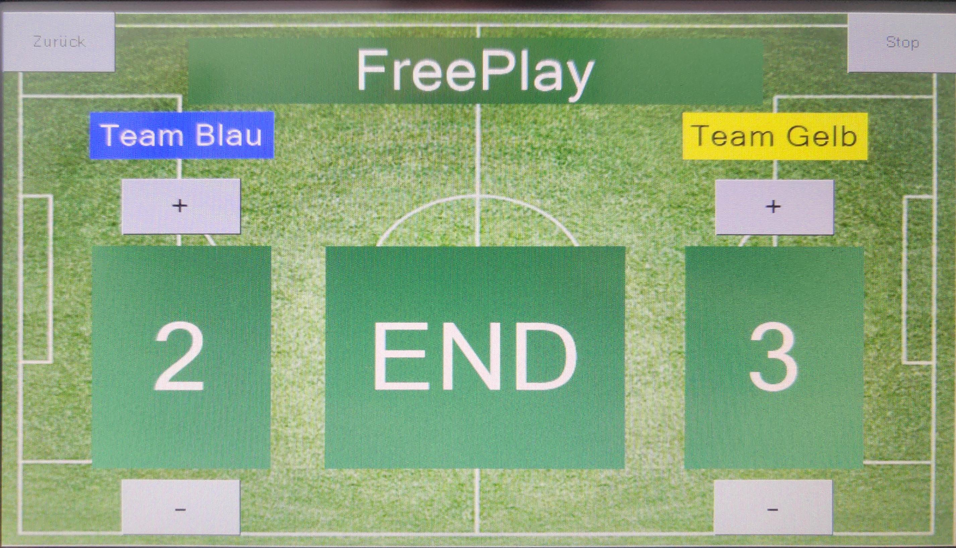
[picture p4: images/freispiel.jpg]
Display Freispiel

<br>
<em>Touch-Display im Freispiel Modus</em>
</div>

**Eigenschaften:**
- ⏱️ **Zeit**: Läuft vorwärts (Elapsed Time)
- 🎯 **Ziel**: Kein automatisches Spielende
- 🏆 **Gewinner**: Manuell bestimmen
- 🔄 **Reset**: Über Menü möglich

**So startest du:**
1. **"MENÜ"** antippen
2. **"Freispiel"** wählen
3. Automatischer Start
4. Spielen bis ihr fertig seid

### 2. ⏰ Zeitspiel (5 oder 10 Minuten)
**Für**: Turnier-Matches, faire Wettkämpfe

<div align="center">
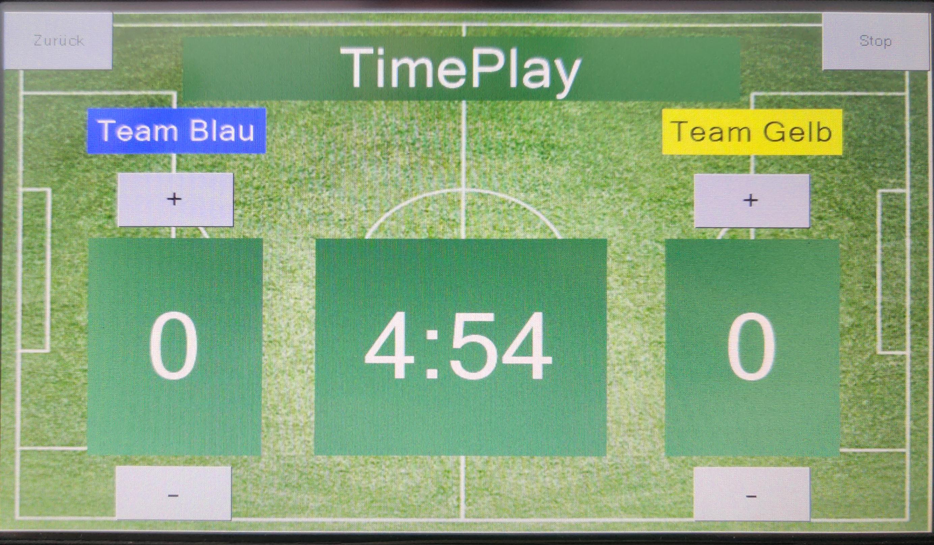
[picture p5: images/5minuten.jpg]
Display 5 Minuten

<br>
<em>5-Minuten Zeitspiel mit Countdown-Timer</em>
</div>

<div align="center">
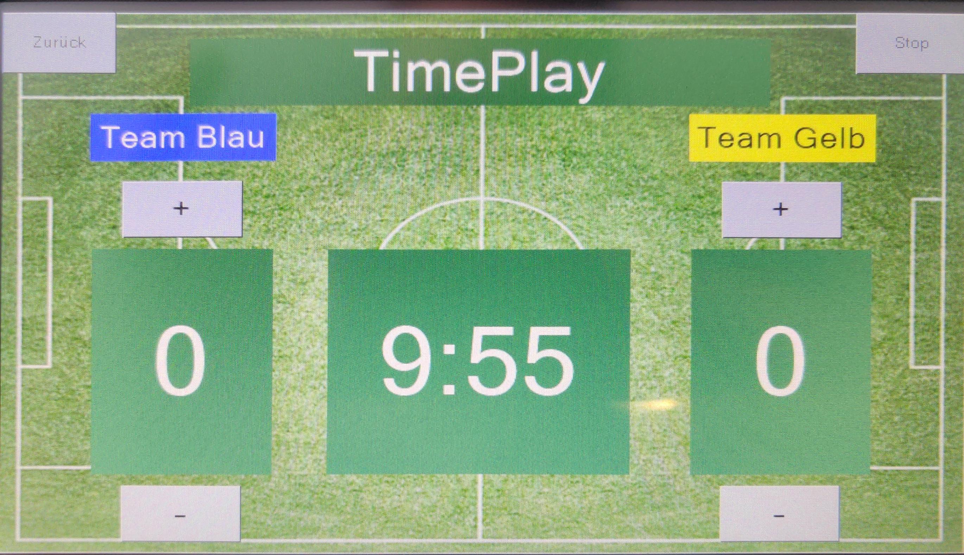
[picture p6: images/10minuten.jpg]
Display 10 Minuten

<br>
<em>10-Minuten Zeitspiel mit Countdown-Timer</em>
</div>

**Verfügbare Zeiten:**
- **"5 Minuten"** - Schnelle Runden
- **"10 Minuten"** - Standard-Matches

**Eigenschaften:**
- ⏱️ **Zeit**: Countdown von 5:00 oder 10:00 bis 0:00
- 🎯 **Ziel**: Mehr Punkte bis Zeitablauf
- 🏆 **Gewinner**: Team mit höherem Score bei 0:00
- 🔄 **Ende**: Automatisch bei Zeitablauf

**So startest du:**
1. **"MENÜ"** antippen
2. **"5 Minuten"** oder **"10 Minuten"** wählen
3. Countdown startet automatisch
4. Bei 0:00 wird der Gewinner angezeigt

### 3. 🏆 Klassisches Spiel (5 oder 10 Punkte)
**Für**: Traditionelle Tischkicker-Matches

<div align="center">
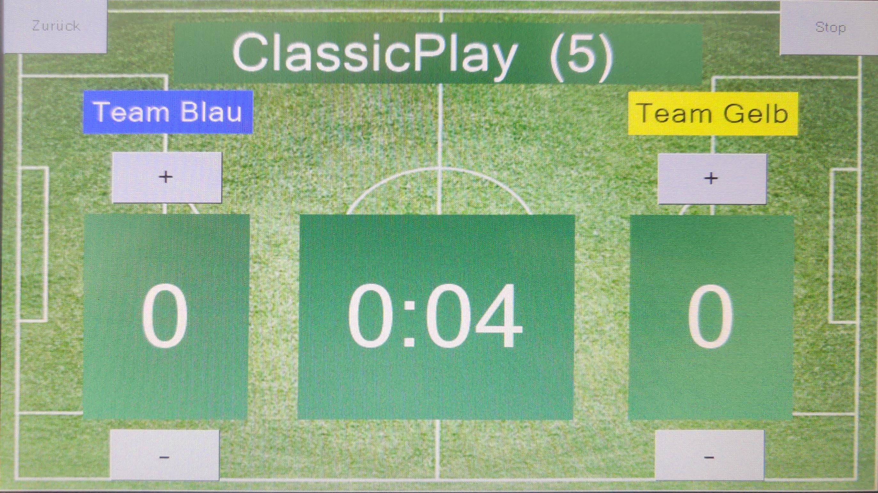
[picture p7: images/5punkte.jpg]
Display 5 Punkte

<br>
<em>Klassisches Spiel bis 5 Punkte</em>
</div>

<div align="center">
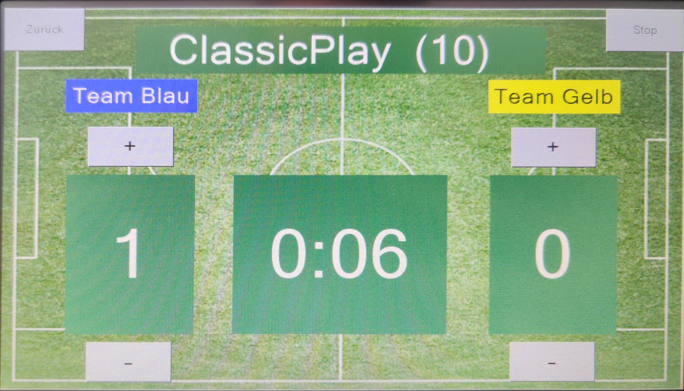
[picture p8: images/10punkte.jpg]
Display 10 Punkte

<br>
<em>Klassisches Spiel bis 10 Punkte</em>
</div>

**Verfügbare Punktziele:**
- **"5 Punkte"** - Schnelle Spiele
- **"10 Punkte"** - Standard-Matches

**Eigenschaften:**
- ⏱️ **Zeit**: Läuft vorwärts (unbegrenzt)
- 🎯 **Ziel**: Erstes Team mit 5 oder 10 Punkten gewinnt
- 🏆 **Gewinner**: Sofort bei Punktziel
- 🔄 **Ende**: Automatisch bei Siegpunkten

**So startest du:**
1. **"MENÜ"** antippen
2. **"5 Punkte"** oder **"10 Punkte"** wählen
3. Spiel startet automatisch
4. Automatisches Spielende bei Punktziel

### 4. 🥇 Best of 3
**Für**: Entscheidende Matches

<div align="center">
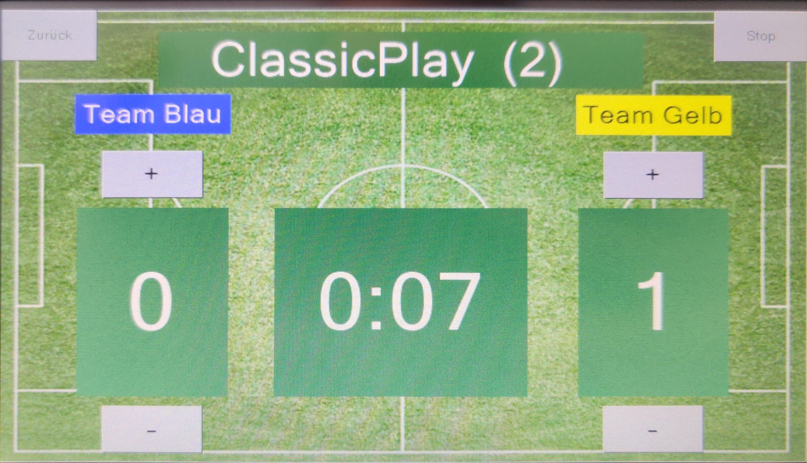
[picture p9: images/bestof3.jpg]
Display Best of 3

<br>
<em>Best of 3 Modus (= Spiel bis 2 Punkte)</em>
</div>

**Eigenschaften:**
- ⏱️ **Zeit**: Läuft vorwärts (unbegrenzt)
- 🎯 **Ziel**: Erstes Team mit 2 Punkten gewinnt
- 🏆 **Gewinner**: Sofort bei 2 Punkten
- 🔄 **Ende**: Automatisch bei 2 Punkten

**So startest du:**
1. **"MENÜ"** antippen
2. **"Best of 3"** wählen
3. Spiel startet automatisch
4. Automatisches Ende bei 2 Punkten

**Hinweis**: Dies ist technisch ein klassisches Spiel bis 2 Punkte, symbolisch für Best of 3 Sätze benannt.

### 📊 Spielmodus-Übersicht

| Modus | Parameter | Spielende | Ideal für |
|---|---|---|---|
| **🆓 Freispiel** | Unbegrenzt | Manuell | Training, Spaß |
| **⏰ 5 Minuten** | 5:00 Countdown | Automatisch | Schnelle Runden |
| **⏰ 10 Minuten** | 10:00 Countdown | Automatisch | Standard-Turniere |
| **🏆 5 Punkte** | Erste 5 Punkte | Automatisch | Kurze Matches |
| **🏆 10 Punkte** | Erste 10 Punkte | Automatisch | Klassisch |
| **🥇 Best of 3** | Erste 2 Punkte | Automatisch | Kurze Entscheidung |

## 📱 Touch-Display Bedienung

### Hauptbildschirm (Während des Spiels)
<div align="center">
Display Hauptbildschirm
<br>
<em>Hauptanzeige während des Spiels - Beispiel: 5 Punkte Modus</em>
</div>

**Display-Elemente (wie in den Screenshots):**
- 🏆 **"SmartKick"** - Logo/Titel oben
- ⏰ **Zeit-Anzeige** - Format abhängig vom Modus
  - Freispiel: Verstrichene Zeit "2:15"
  - Zeitspiel: Countdown "4:45"
  - Klassisch: Verstrichene Zeit "1:30"
- 👥 **"Team Blau: X"** - Team 1 Name und Punktzahl links
- 👥 **"Team Gelb: X"** - Team 2 Name und Punktzahl rechts
- 🎮 **Modus-Anzeige** - Unten (z.B. "ClassicPlay (5)")

**Touch-Bereiche im Spiel:**
- **"+"** Buttons - Punkt manuell hinzufügen (Korrektur)
- **"-"** Buttons - Punkt abziehen (Fehlerkorrektur)
- **"STOP"** Button - Spiel pausieren
- **"MENÜ"** Button - Zurück zum Menü

### Menü-Bildschirm
<div align="center">
Display Menü
<br>
<em>Einstellungsmenü mit 6 vordefinierten Optionen</em>
</div>

**Verfügbare Optionen (exakt wie im Screenshot):**

#### 🎮 Spielmodus-Auswahl
- **"5 Punkte"** - Klassisches Spiel bis 5 Punkte
- **"10 Punkte"** - Klassisches Spiel bis 10 Punkte
- **"Freispiel"** - Unbegrenztes Spiel
- **"Best of 3"** - Spiel bis 2 Punkte
- **"5 Minuten"** - 5-Minuten Zeitspiel
- **"10 Minuten"** - 10-Minuten Zeitspiel

#### 🔙 Navigation
- **"ZURÜCK"** - Zum aktuellen Spiel (falls aktiv)

## 🎯 Praktische Beispiele

### 🏆 Schnelles 5-Minuten Match
<div align="center">
5 Min Beispiel
<br>
<em>5-Minuten Setup - Countdown läuft bereits</em>
</div>

**Einfachste Bedienung:**
1. **"MENÜ"** antippen
2. **"5 Minuten"** wählen (wie im Menü-Screenshot)
3. ✅ **Countdown startet automatisch!**
4. Nach 5:00 Minuten automatisches Ende

### 🎮 Standard 5-Punkte Spiel
<div align="center">
5 Punkte Beispiel
<br>
<em>Klassisches Match - Team Blau führt bereits</em>
</div>

**Klassisches Kicker-Match:**
1. **"MENÜ"** antippen  
2. **"5 Punkte"** wählen
3. ✅ **Display zeigt "ClassicPlay (5)"**
4. Spiel läuft bis erstes Team 5 Punkte hat

### 🏅 10-Punkte Match
<div align="center">
10 Punkte Beispiel
<br>
<em>Längeres klassisches Spiel</em>
</div>

**Für traditionelle Matches:**
1. **"MENÜ"** antippen
2. **"10 Punkte"** wählen
3. ✅ **Display zeigt "ClassicPlay (10)"**
4. Spiel bis erstes Team 10 Punkte erreicht

### 🥇 Best of 3 Finale
<div align="center">
Best of 3 Beispiel
<br>
<em>Entscheidungsspiel - nur 2 Punkte nötig</em>
</div>

**Für wichtige Entscheidungen:**
1. **"MENÜ"** antippen
2. **"Best of 3"** wählen
3. ✅ **Spiel bis 2 Punkte!**
4. Schnelle Entscheidung

### 🆓 Lockeres Training
<div align="center">
Freispiel Beispiel
<br>
<em>Unbegrenztes Spiel ohne Zeitdruck</em>
</div>

**Für Übung ohne Druck:**
1. **"MENÜ"** antippen
2. **"Freispiel"** wählen
3. ✅ **Unbegrenzt spielen!**
4. **"STOP"** wenn ihr fertig seid

## 🔧 Spielstand-Korrektur

### ⚽ Punkt manuell hinzufügen/entfernen
<div align="center">
Korrektur Buttons
<br>
<em>Plus/Minus Buttons sichtbar neben den Punkteständen</em>
</div>

**Falls ein Tor nicht erkannt wurde:**
1. **"+"** Button beim entsprechenden Team antippen
2. Spielstand wird sofort korrigiert (z.B. Team Blau: 2 → 3)
3. Spiel läuft normal weiter

**Falls ein Tor fälschlicherweise gezählt wurde:**
1. **"-"** Button beim entsprechenden Team antippen  
2. Spielstand wird korrigiert (z.B. Team Gelb: 1 → 0)
3. Spiel läuft normal weiter

## 💡 Display-Details aus Screenshots

### 🎮 Spielmodus-Anzeige (Unten)
**Format der Modus-Anzeige:**
- **"ClassicPlay (5)"** = 5 Punkte Spiel (siehe Screenshot)
- **"ClassicPlay (10)"** = 10 Punkte Spiel
- **"FreePlay"** = Freispiel
- **"Best of 3"** = Best of 3
- **"TimePlay (5)"** = 5-Minuten Zeitspiel
- **"TimePlay (10)"** = 10-Minuten Zeitspiel

### ⏰ Zeit-Format (abhängig vom Modus)
- **Verstrichene Zeit**: "1:45" = 1 Minute 45 Sekunden gespielt
- **Countdown**: "4:15" = 4 Minuten 15 Sekunden verbleibend
- **Format**: Immer MM:SS (Minuten:Sekunden)

### 👥 Team-Anzeige
- **Team Links**: "Team Blau: 2" (Name : Punkte)
- **Team Rechts**: "Team Gelb: 1" (Name : Punkte)
- **Standard-Namen**: "Team Blau" und "Team Gelb"
- **Namensänderung**: Nur über serielle Konsole möglich

### 🔧 Button-Layout
**Sichtbar in allen Screenshots:**
- **+/- Buttons**: Neben jedem Teamnamen für Korrekturen
- **STOP Button**: Zum Pausieren
- **MENÜ Button**: Zurück zum Menü (unten rechts)

---

*LED-Lichtshow und automatische Animationen sind nicht implementiert*

## 🔧 Problemlösungen

### ❌ Display reagiert nicht
**Lösungsschritte:**
1. **5 Sekunden warten** - System kann beschäftigt sein
2. **Fester antippen** - Touch muss deutlich sein
3. **Powerbank prüfen** - Ist noch Akku da?
4. **Neustart** - USB-C kurz abstecken

### ⚽ Tor nicht erkannt
**Sofort-Lösung:**
1. **"+"** Button beim entsprechenden Team antippen (wie in Screenshots sichtbar)
2. Spielstand ist korrigiert
3. Weiterspielen

### 🔄 Falscher Spielmodus
**Spielmodus ändern:**
1. **"STOP"** antippen
2. **"MENÜ"** antippen (wie im Screenshot gezeigt)
3. Gewünschten Modus neu wählen
4. Spiel startet automatisch neu

## 🔧 Spielende-Verhalten

**Bei automatischem Spielende:**
- 🏆 **Kurze Gewinner-Anzeige** auf dem normalen Spielbildschirm
- ⏱️ **Endstand bleibt sichtbar** (z.B. "Team Blau: 5, Team Gelb: 3")
- 📱 **Automatischer Rücksprung zum Menü** nach wenigen Sekunden
- 🔄 **Neues Spiel** über Menü-Auswahl starten

**Spielende-Situationen:**
- **Zeitspiel**: Bei 0:00 automatisch zum Menü
- **Klassisch**: Bei Erreichen der Punktzahl (5 oder 10) zum Menü  
- **Best of 3**: Bei 2 Punkten automatisch zum Menü
- **Freispiel**: Nur manuell über "STOP" → "MENÜ"

## 🚀 System starten

### Beim Einschalten
<div align="center">
System Start
<br>
<em>Nach dem Booten erscheint direkt das Menü</em>
</div>

**Startvorgang:**
1. **Powerbank einschalten** (Button drücken)
2. **USB-C einstecken** (ins SmartKick Gehäuse)
3. **5-10 Sekunden warten** (System startet)
4. **Menü erscheint automatisch** (wie im Screenshot)
5. **Spielmodus wählen** → Spiel startet sofort

## 🔧 Spiel-Steuerung

### ⏸️ Spiel pausieren
- **"STOP"** Button antippen (sichtbar in allen Spiel-Screenshots)
- **Spiel pausiert** - Zeit und Punkte bleiben stehen
- **"MENÜ"** antippen → Zurück zur Modus-Auswahl
- **Neuen Modus wählen** → Spiel startet automatisch neu

### 🔄 Spiel beenden
- **Automatisch**: Bei Spielende → automatisch zum Menü
- **Manuell**: "STOP" → "MENÜ" → neuen Modus wählen
- **Sofort-Neustart**: Gleichen Modus erneut wählen

### 📱 Navigation
- **"MENÜ"** Button ist in jedem Spiel verfügbar (unten rechts in Screenshots)
- **Spiel wird pausiert** beim Menü-Aufruf
- **"ZURÜCK"** im Menü → zum pausierten Spiel (falls vorhanden)
- **Neuer Modus** → startet sofort neu (überschreibt pausiertes Spiel)

## 💡 Workflow-Tipps

### 🎮 Schneller Spielwechsel
1. **Aktuelles Spiel läuft** (z.B. "ClassicPlay (5)")
2. **"MENÜ"** antippen
3. **Anderen Modus wählen** (z.B. "10 Minuten")
4. ✅ **Neues Spiel startet sofort!**

### 🔄 Gleichen Modus wiederholen
1. **Spiel zu Ende** → automatisch im Menü
2. **Gleichen Modus erneut antippen** (z.B. "5 Punkte")
3. ✅ **Sofort neues Match 0:0!**

### 🏆 Turnier-Modus
1. **Einmal Modus festlegen** (z.B. "5 Minuten")
2. **Nach jedem Spiel**: Automatisch zurück zum Menü
3. **"5 Minuten" erneut antippen** → nächstes Match
4. **Konsistente Bedienung** für alle Teilnehmer

## ❓ Häufige Fragen (Angepasst)

**Q: Was passiert nach einem Spielende?**  
A: Automatischer Rücksprung zum Menü. Einfach gewünschten Modus erneut wählen für neues Spiel.

**Q: Gibt es einen Game-Over Screen?**  
A: Nein, das System springt direkt zurück zum Menü. Der Endstand ist kurz auf dem Spielbildschirm sichtbar.

**Q: Wie starte ich das System?**  
A: Nach dem Einschalten erscheint automatisch das Menü. Einfach gewünschten Spielmodus antippen.

**Q: Kann ich ein pausiertes Spiel fortsetzen?**  
A: Ja, mit "ZURÜCK" im Menü. Oder neuen Modus wählen für kompletten Neustart.

**Q: Wie schnell kann ich zwischen Spielen wechseln?**  
A: Sehr schnell! Spielende → automatisch im Menü → neuen Modus antippen → sofortiger Start.

---

## 🛠️ Erweiterte Einstellungen (Optional)

*Für erweiterte Konfiguration (individuelle Zeiten, Teamnamen, Debug-Funktionen) gibt es eine serielle Konsole-Steuerung (115200 Baud). Diese ist für den normalen Touch-Betrieb nicht erforderlich.*

**[→ Serielle Konsole Details](./CONSOLE.md)** (Separate Datei für Entwickler)

---

**Zurück zu**: [← Hauptdokumentation](../README.md) | **Hardware**: [Hardware Setup →](HARDWARE.md) | **Software**: [Software Details →](SOFTWARE.md)

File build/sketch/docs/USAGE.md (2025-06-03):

#line 1 "C:\\Projects\\Arduino\\SmartKick\\docs\\USAGE.md"
# Bedienungsanleitung

## 🎮 Spielmodi

### 1. 🆓 Freispiel
**Für**: Lockeres Spielen, Übung, Tests

Display Freispiel
*Touch-Display im Freispiel Modus*

**Eigenschaften:**
- ⏱️ **Zeit**: Läuft vorwärts (Elapsed Time)
- 🎯 **Ziel**: Kein automatisches Spielende
- 🏆 **Gewinner**: Manuell bestimmen
- 🔄 **Reset**: Über Menü möglich

**So startest du:**
1. **"MENÜ"** antippen
2. **"Freispiel"** wählen
3. Automatischer Start
4. Spielen bis ihr fertig seid

### 2. ⏰ Zeitspiel (5 oder 10 Minuten)
**Für**: Turnier-Matches, faire Wettkämpfe

Display 5 Minuten
*5-Minuten Zeitspiel mit Countdown-Timer*

Display 10 Minuten
*10-Minuten Zeitspiel mit Countdown-Timer*

**Verfügbare Zeiten:**
- **"5 Minuten"** - Schnelle Runden
- **"10 Minuten"** - Standard-Matches

**Eigenschaften:**
- ⏱️ **Zeit**: Countdown von 5:00 oder 10:00 bis 0:00
- 🎯 **Ziel**: Mehr Punkte bis Zeitablauf
- 🏆 **Gewinner**: Team mit höherem Score bei 0:00
- 🔄 **Ende**: Automatisch bei Zeitablauf

**So startest du:**
1. **"MENÜ"** antippen
2. **"5 Minuten"** oder **"10 Minuten"** wählen
3. Countdown startet automatisch
4. Bei 0:00 wird der Gewinner angezeigt

### 3. 🏆 Klassisches Spiel (5 oder 10 Punkte)
**Für**: Traditionelle Tischkicker-Matches

Display 5 Punkte
*Klassisches Spiel bis 5 Punkte*

Display 10 Punkte
*Klassisches Spiel bis 10 Punkte*

**Verfügbare Punktziele:**
- **"5 Punkte"** - Schnelle Spiele
- **"10 Punkte"** - Standard-Matches

**Eigenschaften:**
- ⏱️ **Zeit**: Läuft vorwärts (unbegrenzt)
- 🎯 **Ziel**: Erstes Team mit 5 oder 10 Punkten gewinnt
- 🏆 **Gewinner**: Sofort bei Punktziel
- 🔄 **Ende**: Automatisch bei Siegpunkten

**So startest du:**
1. **"MENÜ"** antippen
2. **"5 Punkte"** oder **"10 Punkte"** wählen
3. Spiel startet automatisch
4. Automatisches Spielende bei Punktziel

### 4. 🥇 Best of 3
**Für**: Entscheidende Matches

Display Best of 3
*Best of 3 Modus (= Spiel bis 2 Punkte)*

**Eigenschaften:**
- ⏱️ **Zeit**: Läuft vorwärts (unbegrenzt)
- 🎯 **Ziel**: Erstes Team mit 2 Punkten gewinnt
- 🏆 **Gewinner**: Sofort bei 2 Punkten
- 🔄 **Ende**: Automatisch bei 2 Punkten

**So startest du:**
1. **"MENÜ"** antippen
2. **"Best of 3"** wählen
3. Spiel startet automatisch
4. Automatisches Ende bei 2 Punkten

**Hinweis**: Dies ist technisch ein klassisches Spiel bis 2 Punkte, symbolisch für Best of 3 Sätze benannt.

### 📊 Spielmodus-Übersicht

| Modus | Parameter | Spielende | Ideal für |
|---|---|---|---|
| **🆓 Freispiel** | Unbegrenzt | Manuell | Training, Spaß |
| **⏰ 5 Minuten** | 5:00 Countdown | Automatisch | Schnelle Runden |
| **⏰ 10 Minuten** | 10:00 Countdown | Automatisch | Standard-Turniere |
| **🏆 5 Punkte** | Erste 5 Punkte | Automatisch | Kurze Matches |
| **🏆 10 Punkte** | Erste 10 Punkte | Automatisch | Klassisch |
| **🥇 Best of 3** | Erste 2 Punkte | Automatisch | Kurze Entscheidung |

## 📱 Touch-Display Bedienung

### Hauptbildschirm (Während des Spiels)
Display Hauptbildschirm
*Hauptanzeige während des Spiels - Beispiel: 5 Punkte Modus*

**Display-Elemente (wie in den Screenshots):**
- 🏆 **"SmartKick"** - Logo/Titel oben
- ⏰ **Zeit-Anzeige** - Format abhängig vom Modus
  - Freispiel: Verstrichene Zeit "2:15"
  - Zeitspiel: Countdown "4:45"
  - Klassisch: Verstrichene Zeit "1:30"
- 👥 **"Team Blau: X"** - Team 1 Name und Punktzahl links
- 👥 **"Team Gelb: X"** - Team 2 Name und Punktzahl rechts
- 🎮 **Modus-Anzeige** - Unten (z.B. "ClassicPlay (5)")

**Touch-Bereiche im Spiel:**
- **"+"** Buttons - Punkt manuell hinzufügen (Korrektur)
- **"-"** Buttons - Punkt abziehen (Fehlerkorrektur)
- **"STOP"** Button - Spiel pausieren
- **"MENÜ"** Button - Zurück zum Menü

### Menü-Bildschirm
Display Menü
*Einstellungsmenü mit 6 vordefinierten Optionen*

**Verfügbare Optionen (exakt wie im Screenshot):**

#### 🎮 Spielmodus-Auswahl
- **"5 Punkte"** - Klassisches Spiel bis 5 Punkte
- **"10 Punkte"** - Klassisches Spiel bis 10 Punkte
- **"Freispiel"** - Unbegrenztes Spiel
- **"Best of 3"** - Spiel bis 2 Punkte
- **"5 Minuten"** - 5-Minuten Zeitspiel
- **"10 Minuten"** - 10-Minuten Zeitspiel

#### 🔙 Navigation
- **"ZURÜCK"** - Zum aktuellen Spiel (falls aktiv)

## 🎯 Praktische Beispiele

### 🏆 Schnelles 5-Minuten Match
5 Min Beispiel
*5-Minuten Setup - Countdown läuft bereits*

**Einfachste Bedienung:**
1. **"MENÜ"** antippen
2. **"5 Minuten"** wählen (wie im Menü-Screenshot)
3. ✅ **Countdown startet automatisch!**
4. Nach 5:00 Minuten automatisches Ende

### 🎮 Standard 5-Punkte Spiel
5 Punkte Beispiel
*Klassisches Match - Team Blau führt bereits*

**Klassisches Kicker-Match:**
1. **"MENÜ"** antippen  
2. **"5 Punkte"** wählen
3. ✅ **Display zeigt "ClassicPlay (5)"**
4. Spiel läuft bis erstes Team 5 Punkte hat

### 🏅 10-Punkte Match
10 Punkte Beispiel
*Längeres klassisches Spiel*

**Für traditionelle Matches:**
1. **"MENÜ"** antippen
2. **"10 Punkte"** wählen
3. ✅ **Display zeigt "ClassicPlay (10)"**
4. Spiel bis erstes Team 10 Punkte erreicht

### 🥇 Best of 3 Finale
Best of 3 Beispiel
*Entscheidungsspiel - nur 2 Punkte nötig*

**Für wichtige Entscheidungen:**
1. **"MENÜ"** antippen
2. **"Best of 3"** wählen
3. ✅ **Spiel bis 2 Punkte!**
4. Schnelle Entscheidung

### 🆓 Lockeres Training
Freispiel Beispiel
*Unbegrenztes Spiel ohne Zeitdruck*

**Für Übung ohne Druck:**
1. **"MENÜ"** antippen
2. **"Freispiel"** wählen
3. ✅ **Unbegrenzt spielen!**
4. **"STOP"** wenn ihr fertig seid

## 🔧 Spielstand-Korrektur

### ⚽ Punkt manuell hinzufügen/entfernen
Korrektur Buttons
*Plus/Minus Buttons sichtbar neben den Punkteständen*

**Falls ein Tor nicht erkannt wurde:**
1. **"+"** Button beim entsprechenden Team antippen
2. Spielstand wird sofort korrigiert (z.B. Team Blau: 2 → 3)
3. Spiel läuft normal weiter

**Falls ein Tor fälschlicherweise gezählt wurde:**
1. **"-"** Button beim entsprechenden Team antippen  
2. Spielstand wird korrigiert (z.B. Team Gelb: 1 → 0)
3. Spiel läuft normal weiter

## 💡 Display-Details aus Screenshots

### 🎮 Spielmodus-Anzeige (Unten)
**Format der Modus-Anzeige:**
- **"ClassicPlay (5)"** = 5 Punkte Spiel (siehe Screenshot)
- **"ClassicPlay (10)"** = 10 Punkte Spiel
- **"FreePlay"** = Freispiel
- **"Best of 3"** = Best of 3
- **"TimePlay (5)"** = 5-Minuten Zeitspiel
- **"TimePlay (10)"** = 10-Minuten Zeitspiel

### ⏰ Zeit-Format (abhängig vom Modus)
- **Verstrichene Zeit**: "1:45" = 1 Minute 45 Sekunden gespielt
- **Countdown**: "4:15" = 4 Minuten 15 Sekunden verbleibend
- **Format**: Immer MM:SS (Minuten:Sekunden)

### 👥 Team-Anzeige
- **Team Links**: "Team Blau: 2" (Name : Punkte)
- **Team Rechts**: "Team Gelb: 1" (Name : Punkte)
- **Standard-Namen**: "Team Blau" und "Team Gelb"
- **Namensänderung**: Nur über serielle Konsole möglich

### 🔧 Button-Layout
**Sichtbar in allen Screenshots:**
- **+/- Buttons**: Neben jedem Teamnamen für Korrekturen
- **STOP Button**: Zum Pausieren
- **MENÜ Button**: Zurück zum Menü (unten rechts)

---

*LED-Lichtshow und automatische Animationen sind nicht implementiert*

## 🔧 Problemlösungen

### ❌ Display reagiert nicht
**Lösungsschritte:**
1. **5 Sekunden warten** - System kann beschäftigt sein
2. **Fester antippen** - Touch muss deutlich sein
3. **Powerbank prüfen** - Ist noch Akku da?
4. **Neustart** - USB-C kurz abstecken

### ⚽ Tor nicht erkannt
**Sofort-Lösung:**
1. **"+"** Button beim entsprechenden Team antippen (wie in Screenshots sichtbar)
2. Spielstand ist korrigiert
3. Weiterspielen

### 🔄 Falscher Spielmodus
**Spielmodus ändern:**
1. **"STOP"** antippen
2. **"MENÜ"** antippen (wie im Screenshot gezeigt)
3. Gewünschten Modus neu wählen
4. Spiel startet automatisch neu

## 🔧 Spielende-Verhalten

**Bei automatischem Spielende:**
- 🏆 **Kurze Gewinner-Anzeige** auf dem normalen Spielbildschirm
- ⏱️ **Endstand bleibt sichtbar** (z.B. "Team Blau: 5, Team Gelb: 3")
- 📱 **Automatischer Rücksprung zum Menü** nach wenigen Sekunden
- 🔄 **Neues Spiel** über Menü-Auswahl starten

**Spielende-Situationen:**
- **Zeitspiel**: Bei 0:00 automatisch zum Menü
- **Klassisch**: Bei Erreichen der Punktzahl (5 oder 10) zum Menü  
- **Best of 3**: Bei 2 Punkten automatisch zum Menü
- **Freispiel**: Nur manuell über "STOP" → "MENÜ"

## 🚀 System starten

### Beim Einschalten
System Start
*Nach dem Booten erscheint direkt das Menü*

**Startvorgang:**
1. **Powerbank einschalten** (Button drücken)
2. **USB-C einstecken** (ins SmartKick Gehäuse)
3. **5-10 Sekunden warten** (System startet)
4. **Menü erscheint automatisch** (wie im Screenshot)
5. **Spielmodus wählen** → Spiel startet sofort

## 🔧 Spiel-Steuerung

### ⏸️ Spiel pausieren
- **"STOP"** Button antippen (sichtbar in allen Spiel-Screenshots)
- **Spiel pausiert** - Zeit und Punkte bleiben stehen
- **"MENÜ"** antippen → Zurück zur Modus-Auswahl
- **Neuen Modus wählen** → Spiel startet automatisch neu

### 🔄 Spiel beenden
- **Automatisch**: Bei Spielende → automatisch zum Menü
- **Manuell**: "STOP" → "MENÜ" → neuen Modus wählen
- **Sofort-Neustart**: Gleichen Modus erneut wählen

### 📱 Navigation
- **"MENÜ"** Button ist in jedem Spiel verfügbar (unten rechts in Screenshots)
- **Spiel wird pausiert** beim Menü-Aufruf
- **"ZURÜCK"** im Menü → zum pausierten Spiel (falls vorhanden)
- **Neuer Modus** → startet sofort neu (überschreibt pausiertes Spiel)

## 💡 Workflow-Tipps

### 🎮 Schneller Spielwechsel
1. **Aktuelles Spiel läuft** (z.B. "ClassicPlay (5)")
2. **"MENÜ"** antippen
3. **Anderen Modus wählen** (z.B. "10 Minuten")
4. ✅ **Neues Spiel startet sofort!**

### 🔄 Gleichen Modus wiederholen
1. **Spiel zu Ende** → automatisch im Menü
2. **Gleichen Modus erneut antippen** (z.B. "5 Punkte")
3. ✅ **Sofort neues Match 0:0!**

### 🏆 Turnier-Modus
1. **Einmal Modus festlegen** (z.B. "5 Minuten")
2. **Nach jedem Spiel**: Automatisch zurück zum Menü
3. **"5 Minuten" erneut antippen** → nächstes Match
4. **Konsistente Bedienung** für alle Teilnehmer

## ❓ Häufige Fragen (Angepasst)

**Q: Was passiert nach einem Spielende?**  
A: Automatischer Rücksprung zum Menü. Einfach gewünschten Modus erneut wählen für neues Spiel.

**Q: Gibt es einen Game-Over Screen?**  
A: Nein, das System springt direkt zurück zum Menü. Der Endstand ist kurz auf dem Spielbildschirm sichtbar.

**Q: Wie starte ich das System?**  
A: Nach dem Einschalten erscheint automatisch das Menü. Einfach gewünschten Spielmodus antippen.

**Q: Kann ich ein pausiertes Spiel fortsetzen?**  
A: Ja, mit "ZURÜCK" im Menü. Oder neuen Modus wählen für kompletten Neustart.

**Q: Wie schnell kann ich zwischen Spielen wechseln?**  
A: Sehr schnell! Spielende → automatisch im Menü → neuen Modus antippen → sofortiger Start.

---

## 🛠️ Erweiterte Einstellungen (Optional)

*Für erweiterte Konfiguration (individuelle Zeiten, Teamnamen, Debug-Funktionen) gibt es eine serielle Konsole-Steuerung (115200 Baud). Diese ist für den normalen Touch-Betrieb nicht erforderlich.*

**[→ Serielle Konsole Details](./CONSOLE.md)** (Separate Datei für Entwickler)

---

**Zurück zu**: [← Hauptdokumentation](../README.md) | **Hardware**: [Hardware Setup →](HARDWARE.md) | **Software**: [Software Details →](SOFTWARE.md)

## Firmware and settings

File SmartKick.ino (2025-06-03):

#pragma region                                                                                      // Includes
#include <Arduino.h>                                                                                // Arduino-Basisbibliothek
#include <AltSoftSerial.h>                                                                          // Serielle Kommunikation für Nextion
#pragma endregion

#pragma region                                                                                      // Debug- und Nextion-Einstellungen
byte debugLevel = 1;                                                                                // 0=keine, 1=wichtig, 2=ausführlich
bool nextionEnabled = true;                                                                         // true=aktiviert, false=deaktiviert
#pragma endregion

#pragma region                                                                                      // Debug-Makros für verschiedene Ausgabelevels
#define DEBUG_0_PRINT(x) Serial.print(x)                                                            // Ausgabe immer (Level 0)
#define DEBUG_0_PRINTLN(x) Serial.println(x)
#define DEBUG_0_PRINT_F(x) Serial.print(F(x))                                                       // Mit Flash-Speicher-Optimierung
#define DEBUG_0_PRINTLN_F(x) Serial.println(F(x))

#define DEBUG_1_PRINT(x) \
  if (debugLevel >= 1)   \
  Serial.print(x)                                                                                   // Wichtige Meldungen (Level 1)
#define DEBUG_1_PRINTLN(x) \
  if (debugLevel >= 1)     \
  Serial.println(x)
#define DEBUG_1_PRINT_F(x) \
  if (debugLevel >= 1)     \
  Serial.print(F(x))
#define DEBUG_1_PRINTLN_F(x) \
  if (debugLevel >= 1)       \
  Serial.println(F(x))

#define DEBUG_2_PRINT(x) \
  if (debugLevel >= 2)   \
  Serial.print(x)                                                                                   // Ausführliche Meldungen (Level 2)
#define DEBUG_2_PRINTLN(x) \
  if (debugLevel >= 2)     \
  Serial.println(x)
#define DEBUG_2_PRINT_F(x) \
  if (debugLevel >= 2)     \
  Serial.print(F(x))
#define DEBUG_2_PRINTLN_F(x) \
  if (debugLevel >= 2)       \
  Serial.println(F(x))
#pragma endregion

byte pinArrayInput[2]{
    // Array für Eingangs-Pins
    2,                                                                                              // Lichtschranke Tor 1 (Interrupt)
    3                                                                                               // Lichtschranke Tor 2 (Interrupt)
};

byte pinArrayOutput[4]{
    // Array für RGB-LED-Pins
    4,                                                                                              // Rot-Pin für RGB-LED
    5,                                                                                              // Grün-Pin für RGB-LED
    6,                                                                                              // Blau-Pin für RGB-LED
    7                                                                                               // GND-Pin für RGB-LED
};

volatile unsigned long interruptData[4]{
    // Array für Interrupt-Daten
    0,                                                                                              // Letzte Interrupt-Zeit für Tor 1
    0,                                                                                              // Letzte Interrupt-Zeit für Tor 2
    1000,                                                                                           // Entprellzeit in Millisekunden
    0                                                                                               // Flag für Spielstandaktualisierung
};

unsigned long scoreArray[6]{
    // Array für Spielstand-Daten
    0,                                                                                              // Spielstand Team 1
    0,                                                                                              // Spielstand Team 2
    0,                                                                                              // Sieger-Team (0=unentschieden)
    0,                                                                                              // Spielendestatus (1=beendet)
    0,                                                                                              // Startzeitstempel in Millisek.
    0                                                                                               // Spielzeit in Sekunden
};

byte configArray[4]{
    // Array für Spielkonfiguration
    5,                                                                                              // Spielzeit in Minuten
    10,                                                                                             // Tore zum Sieg
    2,                                                                                              // Spielmodus (0:Free,1:Time,2:Classic)
    0                                                                                               // Control (1:Start,0:Stop,2:Reset)
};

String teamNames[2] = {
    // Array für Teamnamen
    "Team Blau",                                                                                    // Name Team 1 (blau)
    "Team Gelb"                                                                                     // Name Team 2 (gelb)
};

const char *nextionTextFields[7] = {
    // Array für Nextion-Textfelder
    "t0.txt",                                                                                       // Überschrift
    "t1.txt",                                                                                       // Zeit
    "t2.txt",                                                                                       // Teamname 1
    "n0.val",                                                                                       // Spielstand 1
    "t3.txt",                                                                                       // Teamname 2
    "n1.val",                                                                                       // Spielstand 2
    "t4.txt"                                                                                        // Spielmodus
};

class RGBLED
{                                                                                                   // Klasse zur Steuerung der RGB-LED
private:
  byte redPin;                                                                                      // Pin für rote Farbe
  byte greenPin;                                                                                    // Pin für grüne Farbe
  byte bluePin;                                                                                     // Pin für blaue Farbe
  byte gndPin;                                                                                      // Gemeinsamer GND-Pin

public:
  RGBLED(byte redPin, byte greenPin, byte bluePin, byte gndPin)
  {                                                                                                 // Konstruktor mit Pin-Konfiguration
    this->redPin = redPin;
    this->greenPin = greenPin;
    this->bluePin = bluePin;
    this->gndPin = gndPin;
    pinMode(redPin, OUTPUT);                                                                        // Pin-Modus auf Ausgang setzen
    pinMode(greenPin, OUTPUT);
    pinMode(bluePin, OUTPUT);
    pinMode(gndPin, OUTPUT);
    digitalWrite(gndPin, LOW);                                                                      // GND-Pin auf LOW setzen
  }

  void on(byte red, byte green, byte blue)
  {                                                                                                 // LED mit Farbwerten einschalten
    analogWrite(redPin, red);
    analogWrite(greenPin, green);
    analogWrite(bluePin, blue);
  }

  void off()
  {                                                                                                 // LED ausschalten
    analogWrite(redPin, 0);
    analogWrite(greenPin, 0);
    analogWrite(greenPin, 0);                                                                       // Doppelter Aufruf (Fehler)
    analogWrite(bluePin, 0);
  }

  void blink(int times, int duration, byte red, byte green, byte blue)
  {                                                                                                 // LED-Blinkfunktion
    for (int i = 0; i < times; i++)
    {                                                                                               // Wiederholt die Anzahl der Male
      on(red, green, blue);                                                                         // LED einschalten
      delay(duration);                                                                              // Zeit warten
      off();                                                                                        // LED ausschalten
      delay(duration);                                                                              // Zeit warten
    }
  }
};

#pragma region                                                                                      // Call Objects
RGBLED rgbLed(pinArrayOutput[0], pinArrayOutput[1], pinArrayOutput[2], pinArrayOutput[3]);          // RGB-LED-Objekt erstellen
AltSoftSerial nextionSerial;                                                                        // Nextion-Serielle-Verbindung
#pragma endregion

bool debounce(volatile unsigned long &lastmillis)
{                                                                                                   // Entprellfunktion für Interrupts
  if (millis() - lastmillis > interruptData[2])
  {                                                                                                 // Prüft, ob Entprellzeit verstrichen ist
    lastmillis = millis();                                                                          // Aktualisiert Zeitstempel
    return true;                                                                                    // Signal entprellt
  }
  return false;                                                                                     // Signal ignorieren (Prellen)
}

void ISR_Goal1()
{                                                                                                   // Interrupt-Service-Routine für Tor 1
  if (configArray[3] == 1 && debounce(interruptData[0]) && scoreArray[3] == 0)
  {                                                                                                 // Prüft Spielstatus und Entprellung
    scoreArray[0]++;                                                                                // Zählt Tor für Team 1
    rgbLed.blink(1, 500, 0, 0, 255);                                                                // Blaue LED für Team 1 blinken lassen
    interruptData[3] = 1;                                                                           // Anzeige-Update-Flag setzen
  }
}

void ISR_Goal2()
{                                                                                                   // Interrupt-Service-Routine für Tor 2
  if (configArray[3] == 1 && debounce(interruptData[1]) && scoreArray[3] == 0)
  {                                                                                                 // Prüft Spielstatus und Entprellung
    scoreArray[1]++;                                                                                // Zählt Tor für Team 2
    rgbLed.blink(1, 500, 255, 255, 0);                                                              // Gelbe LED für Team 2 blinken lassen
    interruptData[3] = 1;                                                                           // Anzeige-Update-Flag setzen
  }
}

void printScore()
{                                                                                                   // Funktion zur Ausgabe des Spielstands
  static String previousScoreString = "";                                                           // Speichert letzten Spielstand
  static unsigned long lastTimeUpdate = 0;                                                          // Speichert letzten Zeitwert

  String currentScoreString = String(scoreArray[0]) + ":" + String(scoreArray[1]);                  // Aktueller Spielstand als String

  unsigned long currentTime = calculateElapsedTime();                                               // Aktuelle Spielzeit berechnen

  if (currentScoreString != previousScoreString ||
      currentTime != lastTimeUpdate ||
      interruptData[3] == 1)
  {                                                                                                 // Prüft, ob Update nötig ist
    DEBUG_1_PRINTLN_F("=== SPIELSTAND ===");                                                        // Überschrift ausgeben
    DEBUG_1_PRINT(teamNames[0]);
    DEBUG_1_PRINT_F(": ");
    DEBUG_1_PRINTLN(scoreArray[0]);                                                                 // Team 1 Punktestand
    DEBUG_1_PRINT(teamNames[1]);
    DEBUG_1_PRINT_F(": ");
    DEBUG_1_PRINTLN(scoreArray[1]);                                                                 // Team 2 Punktestand

    // Spielmodus anzeigen
    DEBUG_1_PRINT_F("Modus: ");
    switch (configArray[2])
    {
    case 0:
      DEBUG_1_PRINTLN_F("Freies Spiel");                                                            // Modus 0: Freies Spiel
      break;
    case 1:
      DEBUG_1_PRINTLN_F("Zeitspiel");                                                               // Modus 1: Zeitspiel
      break;
    case 2:
      DEBUG_1_PRINTLN_F("Klassisches Spiel");                                                       // Modus 2: Klassisches Spiel
      break;
    default:
      DEBUG_2_PRINTLN_F("Unbekannt");                                                               // Unbekannter Modus
      break;
    }

    // Zeit formatiert anzeigen
    unsigned long minutes, seconds;
    minutes = currentTime / 60;                                                                     // Minuten berechnen
    seconds = currentTime % 60;                                                                     // Sekunden berechnen

    if (configArray[2] == 1)
    {                                                                                               // Bei Zeitspiel verbleibende Zeit
      DEBUG_1_PRINT_F("Verbleibende Zeit: ");
    }
    else
    {                                                                                               // Sonst verstrichene Zeit
      DEBUG_1_PRINT_F("Verstrichene Zeit: ");
    }
    DEBUG_1_PRINT(minutes);                                                                         // Minuten ausgeben
    DEBUG_1_PRINT_F(":");                                                                           // Doppelpunkt ausgeben
    if (seconds < 10)
      DEBUG_1_PRINT_F("0");                                                                         // Führende Null bei einstelligen Sekunden
    DEBUG_1_PRINTLN(seconds);                                                                       // Sekunden ausgeben

    previousScoreString = currentScoreString;                                                       // Werte für nächsten Vergleich speichern
    lastTimeUpdate = currentTime;
    interruptData[3] = 0;                                                                           // Update-Flag zurücksetzen
  }
}

void printConfig()
{                                                                                                   // Konfiguration ausgeben
  DEBUG_0_PRINTLN_F("=== KONFIGURATION ===");                                                       // Überschrift

  DEBUG_0_PRINT_F("Spielmodus: ");                                                                  // Spielmodus anzeigen
  switch (configArray[2])
  {
  case 0:
    DEBUG_0_PRINTLN_F("Freies Spiel");
    break;
  case 1:
    DEBUG_0_PRINTLN_F("Zeitspiel");
    break;
  case 2:
    DEBUG_0_PRINTLN_F("Klassisches Spiel");
    break;
  default:
    DEBUG_2_PRINTLN_F("Unbekannt");
    break;
  }

  DEBUG_0_PRINT_F("Spielzeit: ");                                                                   // Spielzeit in Minuten
  DEBUG_0_PRINT(configArray[0]);
  DEBUG_0_PRINTLN_F(" Minuten");

  DEBUG_0_PRINT_F("Tore zum Sieg: ");                                                               // Benötigte Tore zum Sieg
  DEBUG_0_PRINTLN(configArray[1]);

  DEBUG_0_PRINT_F("Debug-Level: ");                                                                 // Aktueller Debug-Level
  DEBUG_0_PRINTLN(debugLevel);

  DEBUG_0_PRINT_F("Nextion-Display: ");                                                             // Nextion-Display-Status
  DEBUG_0_PRINTLN(nextionEnabled ? "Aktiviert" : "Deaktiviert");

  DEBUG_0_PRINTLN_F("-------------------");                                                         // Abschlusszeile
}

void initializeGameTime()
{                                                                                                   // Spielzeit initialisieren
  scoreArray[4] = millis();                                                                         // Aktueller Zeitstempel speichern
  if (configArray[2] == 1 || configArray[2] == 2)
  {                                                                                                 // Bei Zeit- oder Klassischem Spiel
    scoreArray[5] = configArray[0] * 60;                                                            // Minuten in Sekunden umrechnen
  }
}

unsigned long getElapsedTime()
{                                                                                                   // Verstrichene Zeit berechnen
  return (millis() - scoreArray[4]) / 1000;                                                         // Zeit in Sekunden seit Spielbeginn
}

unsigned long getRemainingTime()
{                                                                                                   // Verbleibende Zeit berechnen
  unsigned long elapsedTime = getElapsedTime();                                                     // Verstrichene Zeit
  return scoreArray[5] > elapsedTime ? scoreArray[5] - elapsedTime : 0;                             // Verbleibende Zeit oder 0
}
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
void loop()
{                                                                                                   // Hauptschleife (wird wiederholt ausgeführt)
  if (Serial.available() > 0)
  {                                                                                                 // Wenn Daten von serieller Schnittstelle
    delay(50);                                                                                      // Kurze Verzögerung für vollständige Daten

    String input = "";                                                                              // Alle verfügbaren Zeichen lesen
    while (Serial.available() > 0)
    {                                                                                               // Solange Daten verfügbar
      char c = Serial.read();                                                                       // Zeichen lesen
      if ((c == '\r' || c == '\n') && input.length() == 0)
      {                                                                                             // CR/LF am Anfang ignorieren
        continue;
      }
      if (c == '\r' || c == '\n')
      {                                                                                             // CR/LF beendet Eingabe
        break;
      }
      input += c;                                                                                   // Zeichen zum Input hinzufügen
    }

    input.trim();                                                                                   // Leerzeichen entfernen
    if (input.length() > 0)
    {                                                                                               // Wenn Input nicht leer
      DEBUG_2_PRINT_F("Eingabe von Serial: ");
      DEBUG_2_PRINTLN(input);

      DEBUG_2_PRINT_F("HEX: ");                                                                     // Hex-Darstellung für Debug
      for (unsigned int i = 0; i < input.length(); i++)
      {
        DEBUG_2_PRINT(String((byte)input.charAt(i), HEX));
        DEBUG_2_PRINT_F(" ");
      }
      DEBUG_2_PRINTLN_F("");

      processCommand(input);                                                                        // Befehl verarbeiten
    }
  }

  if (nextionEnabled)
  {                                                                                                 // Nextion Kommunikation
    if (nextionSerial.available() > 0)
    {                                                                                               // Wenn Daten vom Display
      String input = readNextionResponse();                                                         // Antwort lesen
      DEBUG_2_PRINT("Eingabe von Nextion: ");
      DEBUG_2_PRINTLN(input);

      processCommand(input);                                                                        // Befehl verarbeiten
    }

    updateNextion();                                                                                // Display aktualisieren
  }

  printScore();                                                                                     // Spielstand anzeigen
  checkGameEnd();                                                                                   // Spielende prüfen
}

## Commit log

2025-03-01 Updated Buzzer to tone
    [SmartKick.ino]
2025-03-05 Test with LED
2025-03-05 Interrupts überarbeitet
2025-03-05 feat: Add setGameMode function and improve game mode handling
    - Added setGameMode function to set the game mode and print the corresponding message.
    - Updated resetGame function to set the game mode to FreePlay after reset.
    - Modified setup function to use setGameMode for setting the initial game mode to FreePlay.
    - Improved game mode handling in updateArray function using setGameMode.
    - Ensured that game mode is set correctly and the game is started accordingly.
    - Adjusted printScore function to center the time display.
    - Updated comments for better clarity and consistency.
    [SmartKick.ino]
2025-03-06 feat: Improve game mode handling and loop structure
    - Adjusted printScore function to center the time display and count down in TIME_PLAY mode.
    - Removed interruptData[3] flag as printScore already checks buffer changes.
    - Cleaned up loop function to follow the order of game operations:
    1. P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
2025-03-06 Füge bin- und .vscode-Ordner zur .gitignore hinzu
2025-03-06 Initiales Commit des SmartKick-Projekts
    - Füge Hauptcode für die intelligente Torerfassung hinzu
    - Implementiere Funktionen zur Spielstandsanzeige und Spielsteuerung
    - Integriere RGB-LED-Steuerung für visuelle Effekte
    - Implementiere serielle Schnittstelle zur Konfiguration und Steuerung
    - Füge .gitignore hinzu, um bin- und .vscode-Ordner auszuschließen
    [Gehäuse v14.f3d, Rückwand.stl]
2025-03-10 feat: Add Nextion display integration and update commands
    - Implemented Nextion display integration for real-time game updates.
    - Added commands to set and get game configurations and scores.
    - Updated RGBLED class to control RGB LEDs for game status indication.
    - Added debounce function for reliable sensor input handling.
    - Implemented ISR functions for goal detection and score updating.
    - Added functions to check game end conditions and update game status.
    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
2025-03-20 feat: Gesamtverbesserungen und Spielstandbegrenzung
    - Implementiert Spielstandbegrenzung von 0-99 in handleSetScore()
    - Verhindert negative Spielstände und begrenzt nach oben auf 99
    - Optimiert Nextion-Display Kommunikation mit verbessertem Response-Handling
    - Behebt doppelten analogWrite-Aufruf im RGBLED::off()
    - Verbessert startGame() mit schnellerer Initialisierung
    - Einheitliche Codekommentierung nach Spaltenformat
    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
2025-06-03 docs: Vollständige Überarbeitung der Projektdokumentation
    - README.md: Aktualisierte Hardware-Kosten und Features-Beschreibung
    - USAGE.md: Detaillierte Bedienungsanleitung mit echten Display-Screenshots
    * Korrigierte Spielmodi-Namen entsprechend der Implementierung
    * Hinzugefügte Touch-Bedienung für alle 6 Modi (5/10 Punkte, 5/10 Minuten, Freispiel, Best of 3)
    * Praktische Beispiele und Troubleshooting-Guides
    - CONSOLE.md: Neue serielle Konsolen-Dokumentation für Entwickler
    * Vollständige Befehlsreferenz (GET/SET/NXT/HELP)
    * Debug-Level Konfiguration und erweiterte Funktionen
    - HARDWARE.md: Placeholder für Hardware-Setup (Schaltplan folgt)
    - SOFTWARE.md: Placeholder für Sof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
    [SmartKick.ino]
2025-06-03 docs: Vollständige Dokumentation mit Screenshots hinzugefügt
    - Alle Spielmodi-Screenshots in docs/images/ hinzugefügt
    - HARDWARE.md und SOFTWARE.md erstellt
    - Ordnerstruktur vervollständigt
    - Dokumentation jetzt vollständig funktional
    [Gehäuse v14.f3d, Gehäuse v18.f3d, Rückwand.stl]
2025-06-10 Update HARDWARE.md
    PIN Belegung aktualisiert.

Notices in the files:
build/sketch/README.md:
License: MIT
